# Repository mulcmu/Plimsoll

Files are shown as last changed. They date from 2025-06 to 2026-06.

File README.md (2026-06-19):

# Plimsoll

Prototype designs for klipper load cell ADC implementations.

### Alpha Test

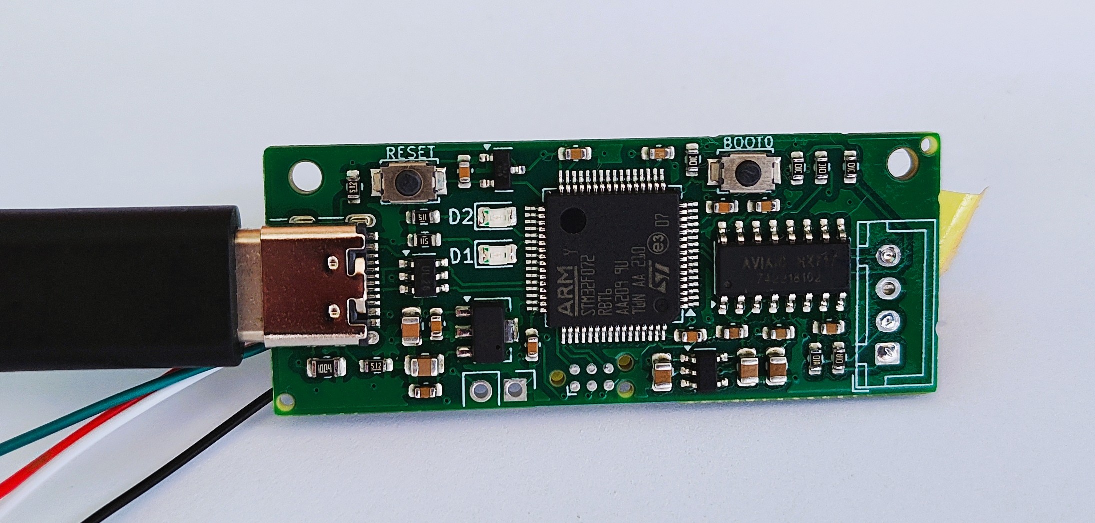
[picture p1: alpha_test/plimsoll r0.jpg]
plimsoll


STM32F072 and HX717 based strain gauge for use as a Klipper load cell.

Initial batch ordered for testing with JLCPCB.  About 5.5 USD cost per board.

Firmware and configuration tested with [current community test branch](https://github.com/garethky/klipper/tree/load-cell-probe-community-testing).

Smallish size, 20x50 mm footprint.  M2.5 mounting holes.  Fab house added the smaller tooling holes...

4 layer PCB all parts on top side.

MCU selected for crystal less USB operation with minimum of 64k flash for firmware.

Separate low noise, high PSRR for analog Vdd supply.

HX717 default data rate 320 Hz.  Adjustable with solder jumpers.

> [!NOTE]
>
> Crystal less main clock is problematic with Klipper and maybe the HX717 code.
>
> Works fine 90% of time, but suffers from occasional timeouts during probes.

### Mini HX717 / Mini ADS1220

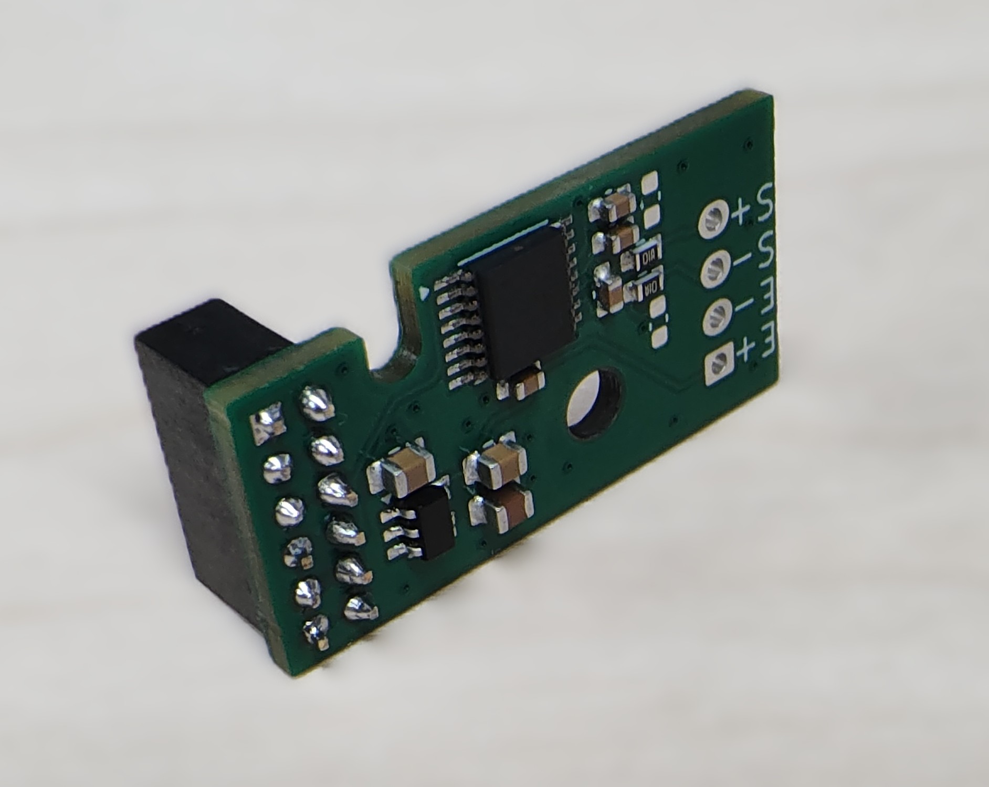
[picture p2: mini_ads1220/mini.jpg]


Addon for a FYSETC H36 **v1** Toolhead board.  Uses the 2x6 2mm expansion pin headers for mounting.  Hardware spi works for the [H36_COMBO](https://wiki.fysetc.com/docs/H36-Combo).  The [H36_COMBO_V2](https://wiki.fysetc.com/docs/H36-Combo-V2) changed the header pins.

Straight needle 2mm 2x6 female pin header (4.3mm plastic body) fits with 6mm standoff but doesn't clear the _IO.0+1_ with a cable installed. A bent needle 2mm 2x6 header works (6mm plastic body) with 8mm standoff after bending the pins to be straight.

4 layer PCB all parts on top side.

Separate low noise, high PSRR for analog Vdd supply.

HX717 data rate 320 Hz.  

Klipper configs for ADS1220/HX717 configs.  
Users have reported __software SPI__ is functional on the v2 boards.

H36 V1
```
sensor_type: ads1220
cs_pin: toolhead:PB6
spi_bus: spi1a
data_ready_pin: toolhead:PC13

sensor_type: hx717
sclk_pin: toolhead:PB3
dout_pin: toolhead:PB4
```

H36 V2
```
sensor_type: ads1220
cs_pin: toolhead:PA14
data_ready_pin: toolhead:PA1
spi_software_sclk_pin:PB7
spi_software_mosi_pin:PB13
spi_software_miso_pin:PA15
spi_speed: 256000

sensor_type: hx717
sclk_pin: toolhead:PB7
dout_pin: toolhead:PA15
```

### 4ch Underbed

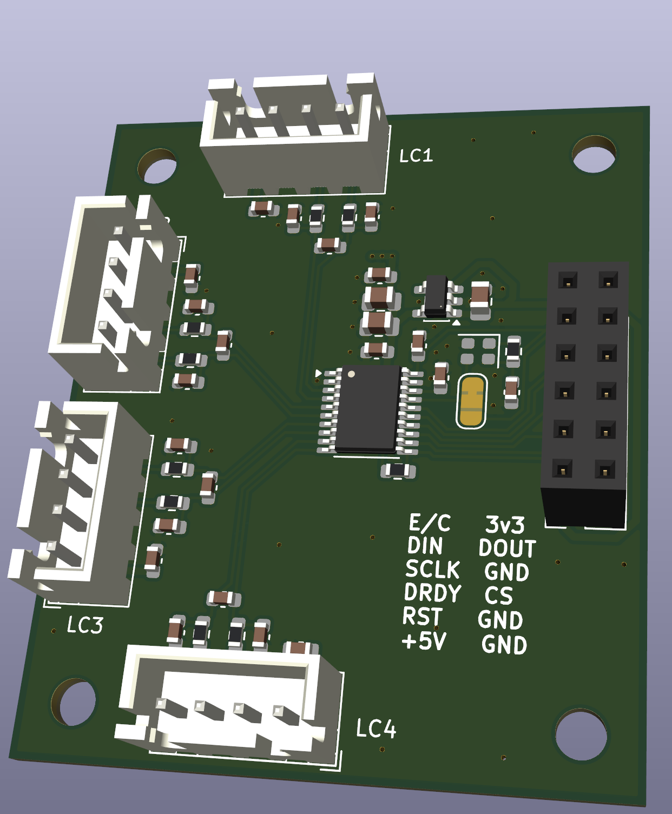
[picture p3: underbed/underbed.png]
mini


4 channel ADS131M04 for underbed applications.  Each load cell can be individually measured and digitally summed.

8.192 MHz clock hardware generator.

Separate low noise, high PSRR for analog Vdd supply.

### Todo:

- [X] Test 2mm pin header fitup on mini pcb
- [x] Test mini ads1220
- [x] Test mini hx717
- [ ] Test underbed pcb
- [ ] ADS131M04 firmware and klipper support

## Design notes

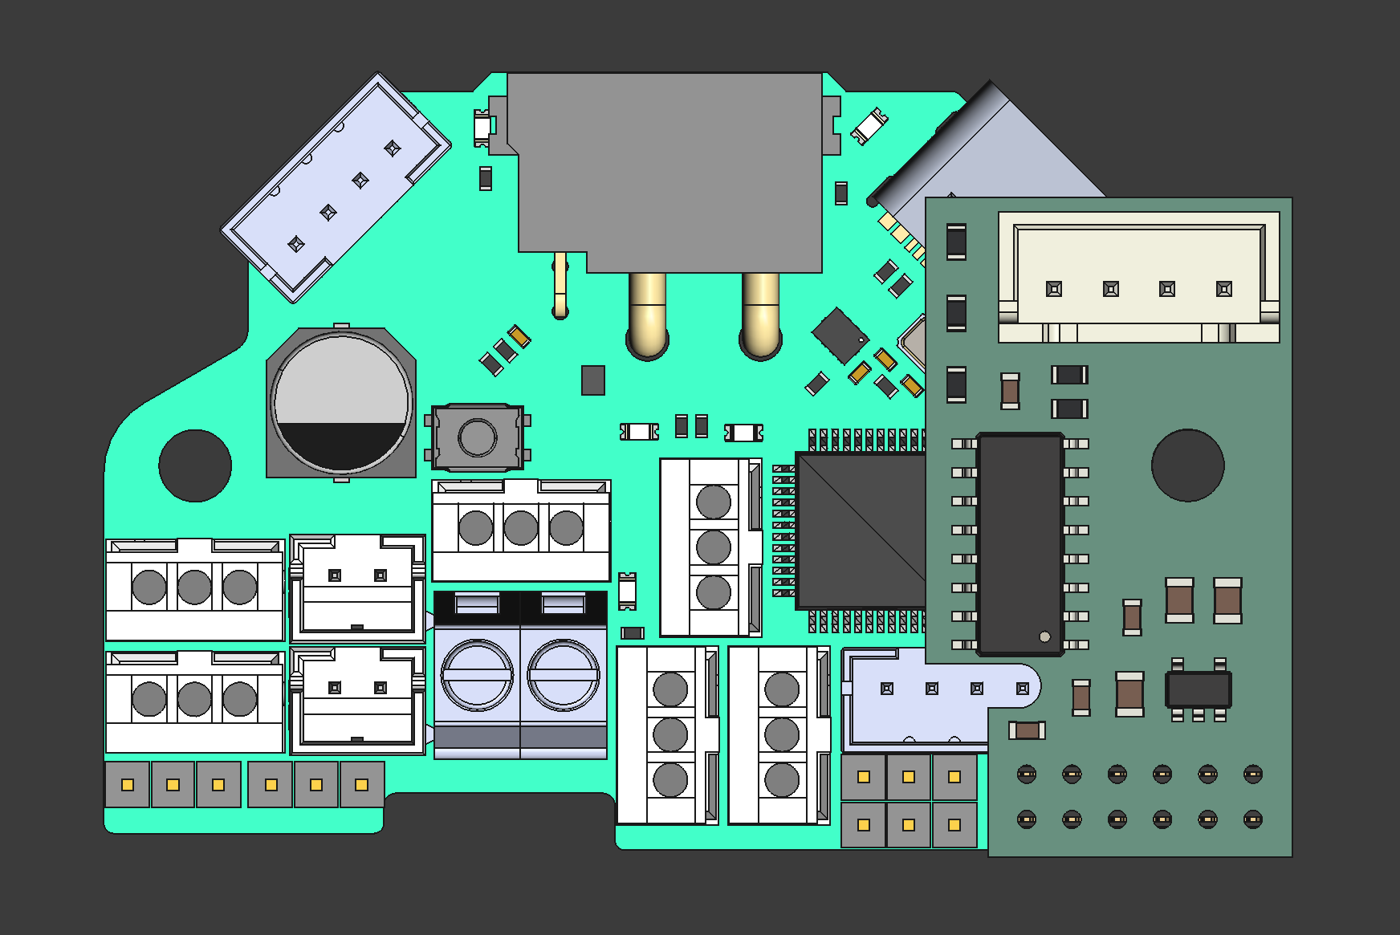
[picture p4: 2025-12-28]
mini_hx717/Screenshot 2025-12-27 220505.png

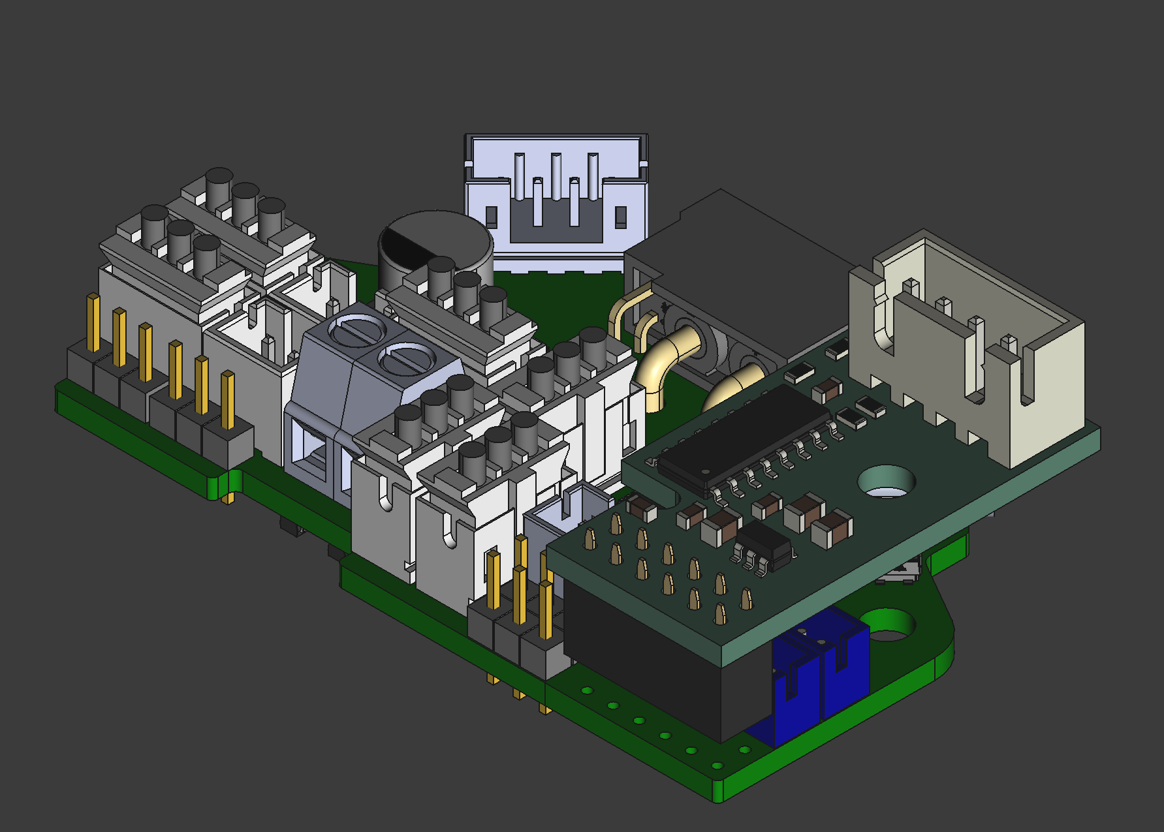
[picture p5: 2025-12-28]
mini_hx717/Screenshot 2025-12-27 220617.png

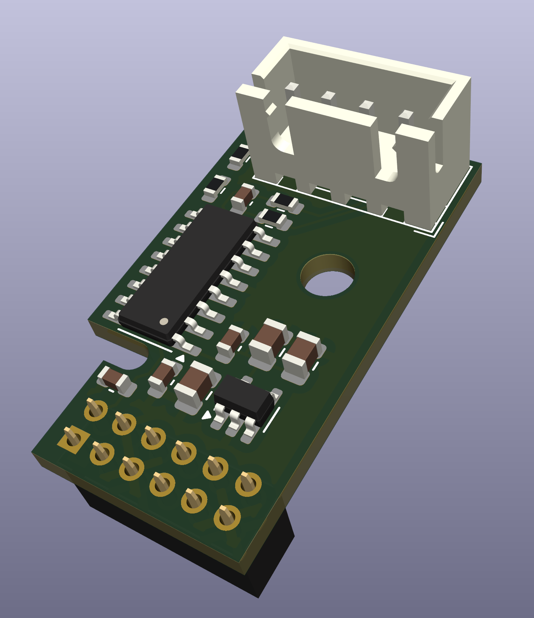
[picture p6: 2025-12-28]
mini_hx717/Screenshot 2025-12-27 220855.png

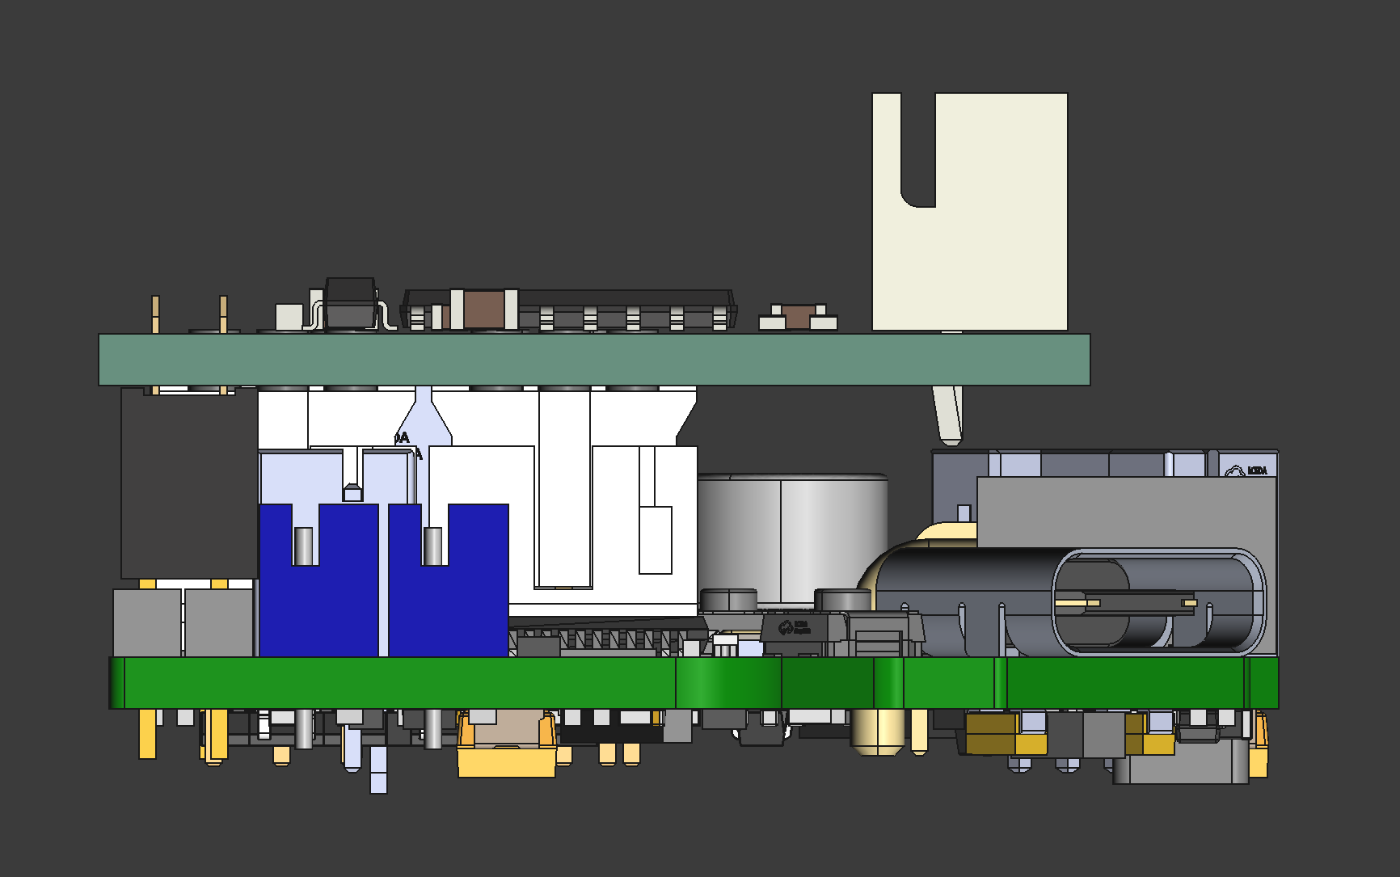
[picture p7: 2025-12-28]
mini_hx717/Screenshot 2025-12-27 220809.png

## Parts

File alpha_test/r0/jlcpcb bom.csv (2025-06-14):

Value | Reference | Footprint | LCSC PN
100n | C1 C3 C5 C7 C8 C9 C12 C13 C14 C15 C16 C17 | Capacitor_SMD:C_0603_1608Metric | C14663
10u | C2 C4 C11 | Capacitor_SMD:C_0805_2012Metric | C15850
1u | C6 C10 | Capacitor_SMD:C_0805_2012Metric | C28323
GRN | D1 D2 | LED_SMD:LED_0805_2012Metric | C2297
USB_C | J2 | Connector_USB:USB_C_Receptacle_G-Switch_GT-USB-7010ASV | C2988369
1M | R1 | Resistor_SMD:R_0805_2012Metric | C17514
10k | R4 R10 R11 R12 | Resistor_SMD:R_0603_1608Metric | C25804
5k1 | R5 R6 | Resistor_SMD:R_0603_1608Metric | C23186
100 | R7 R8 | Resistor_SMD:R_0603_1608Metric | C22775
510 | R13 R14 | Resistor_SMD:R_0603_1608Metric | C23193
RESET | SW1 | plimsoll-Library:push_button | C720477
BOOT0 | SW2 | plimsoll-Library:push_button | C720477
USBLC6-2SC6 | U1 | Package_TO_SOT_SMD:SOT-23-6 | C7519
APX803L20-29SA-7 | U2 | Package_TO_SOT_SMD:SOT-23 | C2067355
STM32F072RBTx | U3 | Package_QFP:LQFP-64_10x10mm_P0.5mm | C46046
AP2205-3.3 | U4 | Package_TO_SOT_SMD:SOT-89-3 | C5205181
RS3236-3.3 | U5 | Package_TO_SOT_SMD:SOT-23-5 | C379349
HX717 | U6 | Package_SO:SOP-16_3.9x9.9mm_P1.27mm | C575394

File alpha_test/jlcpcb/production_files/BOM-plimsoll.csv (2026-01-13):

Comment | Designator | Footprint | LCSC | Quantity
100n | C1,C13,C14,C15,C16,C17,C3,C5 | C_0603_1608Metric | C14663 | 8
10k | R4 | R_0603_1608Metric | C25804 | 1
10u | C2,C4 | C_0805_2012Metric | C15850 | 2
1M | R1 | R_0805_2012Metric | C17514 | 1
20pf | C7,C8 | C_0603_1608Metric | C14663 | 2
510 | R13,R14 | R_0603_1608Metric | C23193 | 2
5k1 | R5,R6 | R_0603_1608Metric | C23186 | 2
AP2205-3.3 | U4 | SOT-89-3 | C5205181 | 1
APX803L20-29SA-7 | U2 | SOT-23 | C2067355 | 1
BOOT0 | BOOT | push_button | C720477 | 1
GRN | D1,D2 | LED_0805_2012Metric | C2297 | 2
RESET | RESET | push_button | C720477 | 1
STM32F072RBTx | U3 | LQFP-64_10x10mm_P0.5mm | C46046 | 1
USBLC6-2SC6 | U1 | SOT-23-6 | C7519 | 1
USB_C | J2 | USB_C_Receptacle_G-Switch_GT-USB-7010ASV | C2988369 | 1
Crystal_GND24 | Y2 | Crystal_SMD_3225-4Pin_3.2x2.5mm_HandSoldering |  | 1
Conn_01x18 | J3 | PinHeader_1x18_P2.54mm_Vertical |  | 1
Conn_01x18 | J7 | PinHeader_1x18_P2.54mm_Vertical |  | 1
Conn_01x18 | J6 | PinHeader_1x18_P2.54mm_Vertical |  | 1
Conn_01x18 | J5 | PinHeader_1x18_P2.54mm_Vertical |  | 1

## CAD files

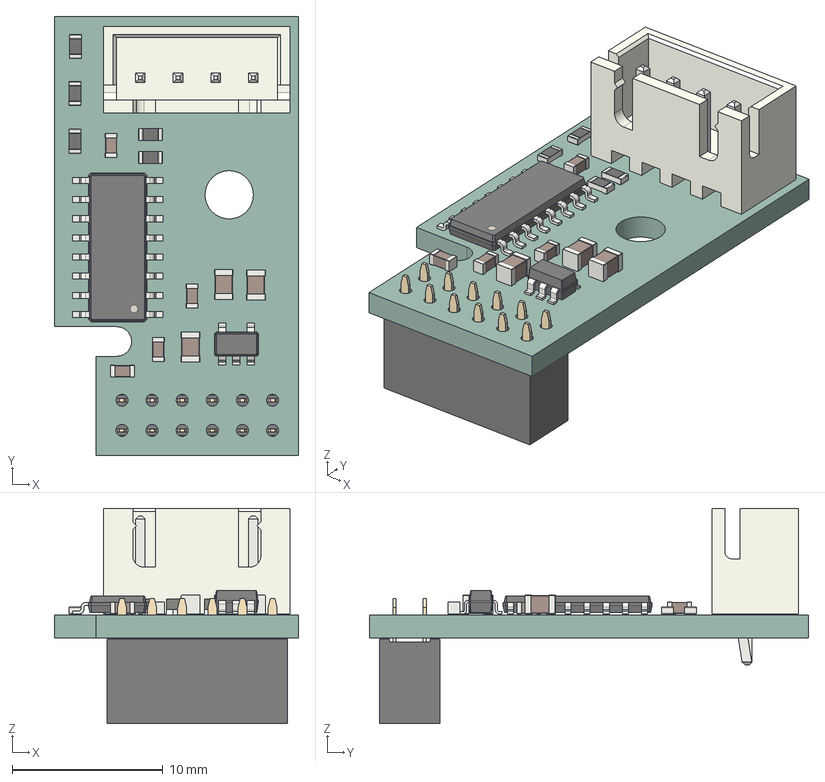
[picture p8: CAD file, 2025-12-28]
mini_hx717/plimsoll.step
16.2 x 29.1 x 14.3 mm
R_0603_1608Metric x 5
JST_XH_B4B-XH-A_1x04_P2.50mm_Vertical
C_0603_1608Metric x 4
C_0805_2012Metric x 3
SOT-23-5
SOP-16_3.9x9.9mm_P1.27mm
PinSocket_2x06_P2.00mm_Vertical
plimsoll_PCB

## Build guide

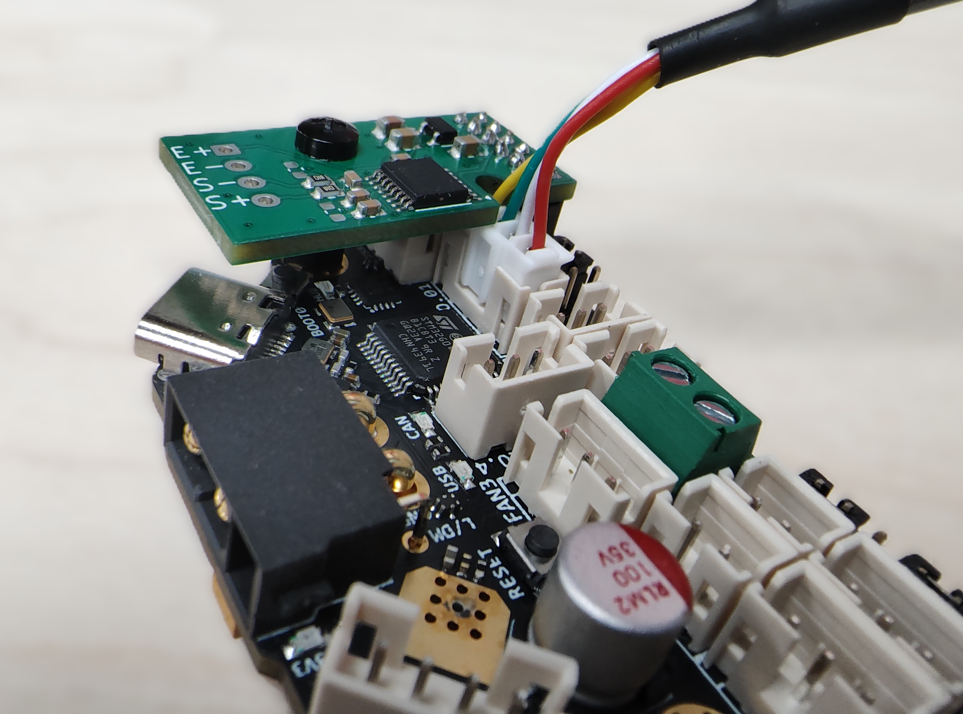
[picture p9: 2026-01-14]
mini_ads1220/installed.jpg

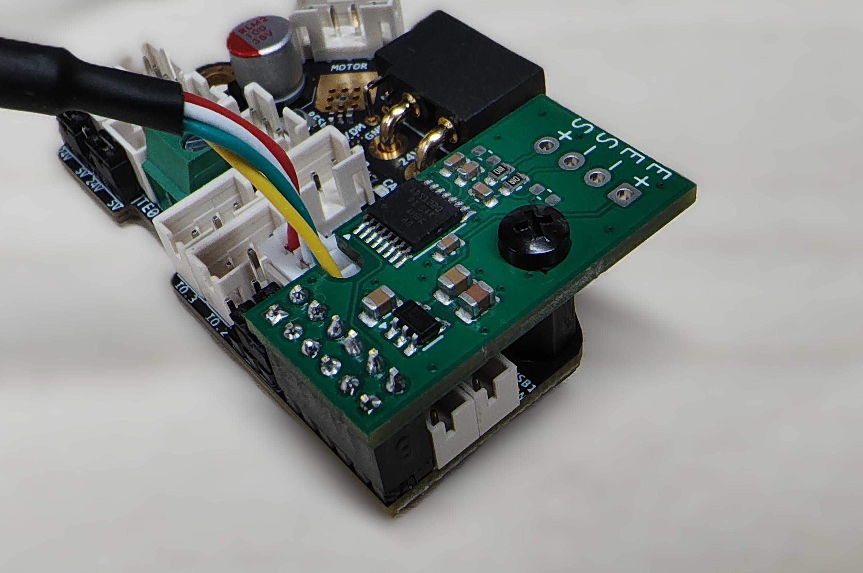
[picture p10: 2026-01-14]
mini_ads1220/installed2.jpg

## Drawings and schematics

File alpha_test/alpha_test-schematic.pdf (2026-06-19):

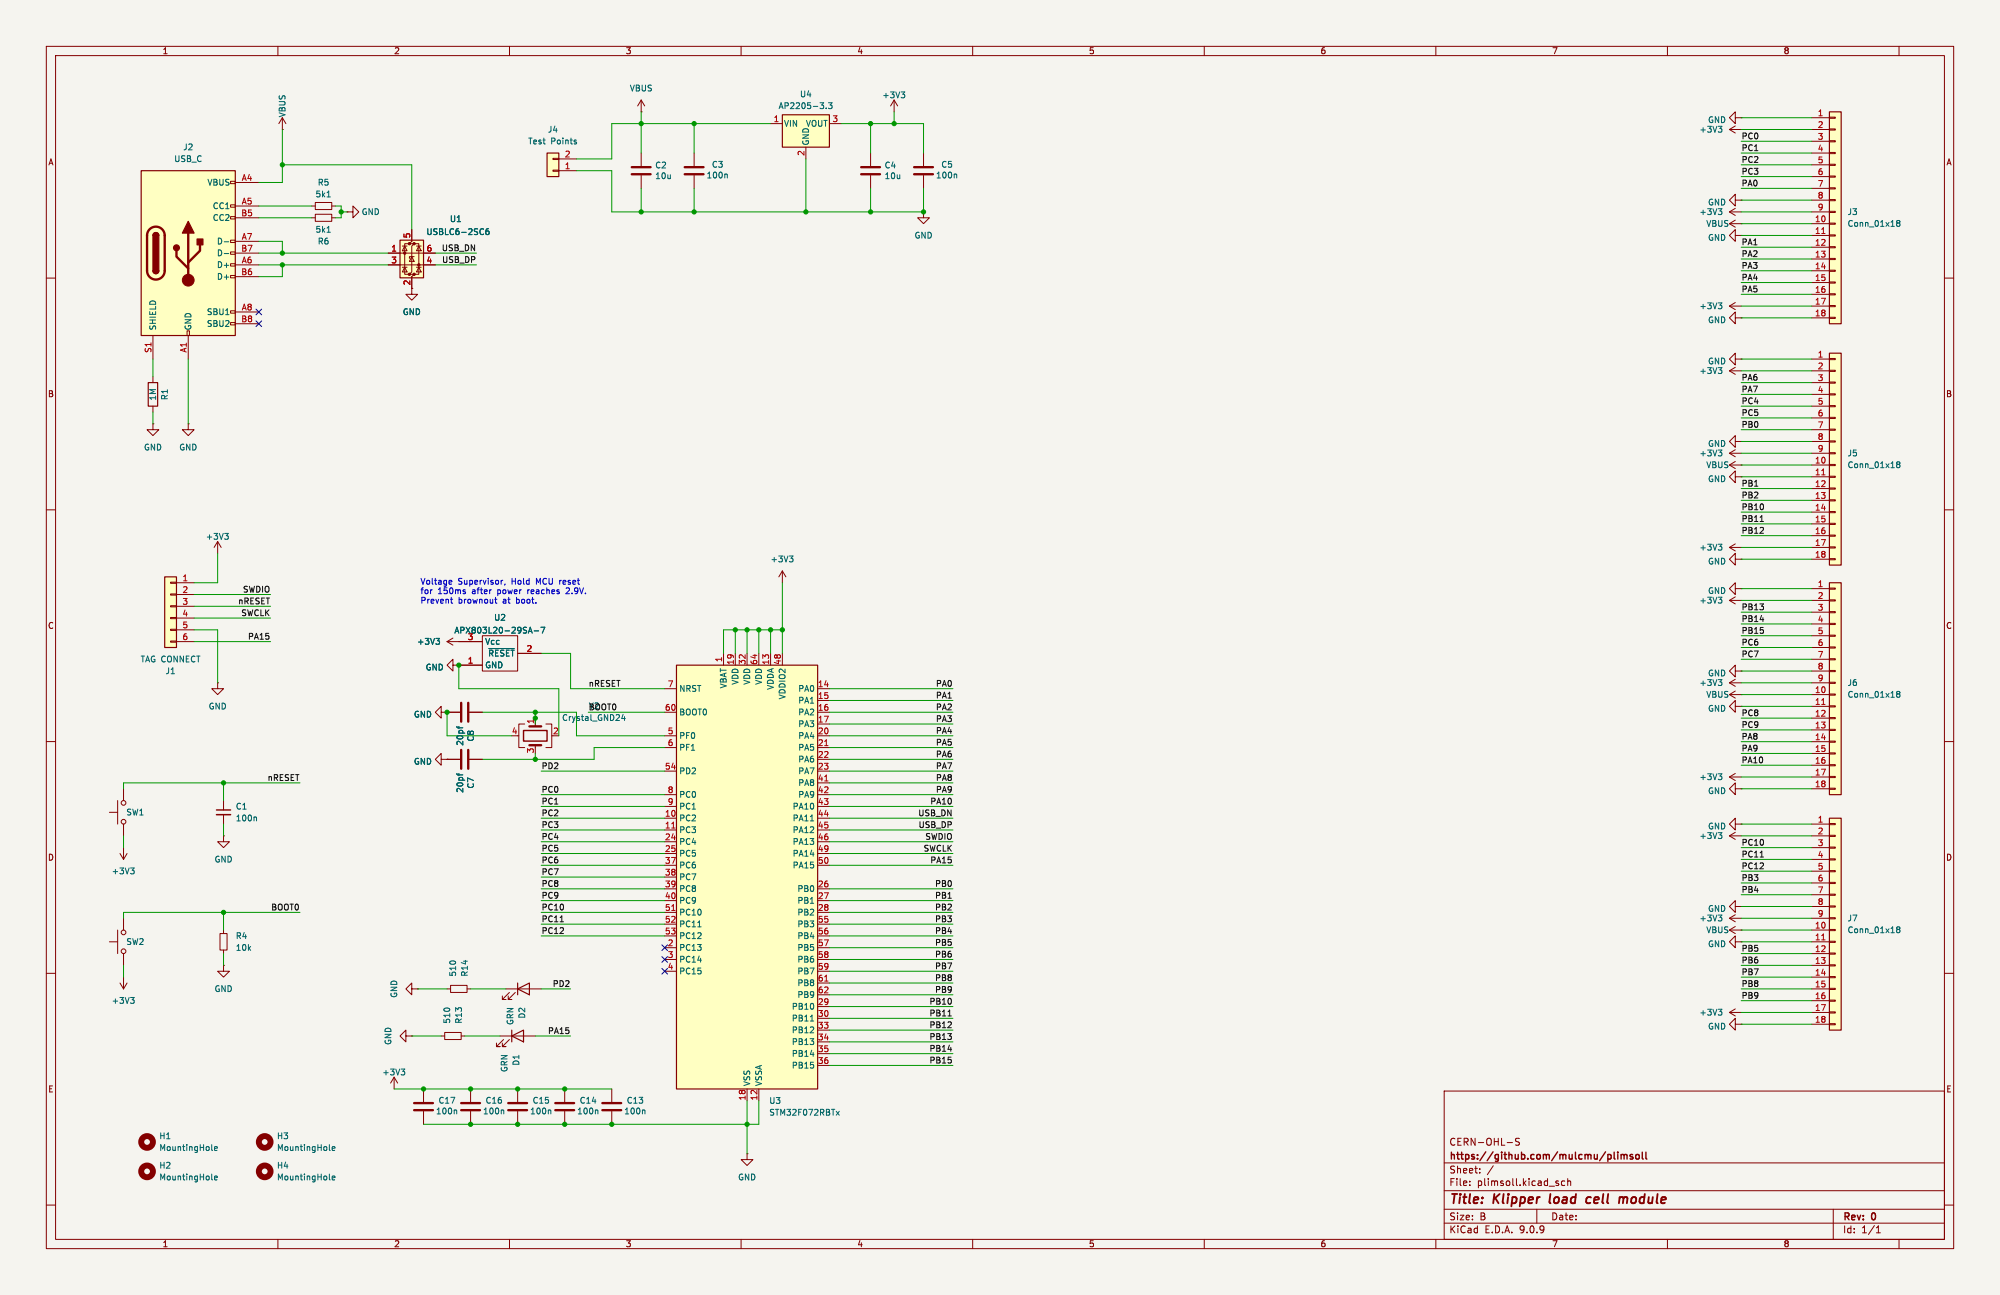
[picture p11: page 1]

File: plimsoll.kicad_sch Sheet: / https://github.com/mulcmu/plimsoll CERN-OHL-S

Id: 1/1 Title: Klipper load cell module

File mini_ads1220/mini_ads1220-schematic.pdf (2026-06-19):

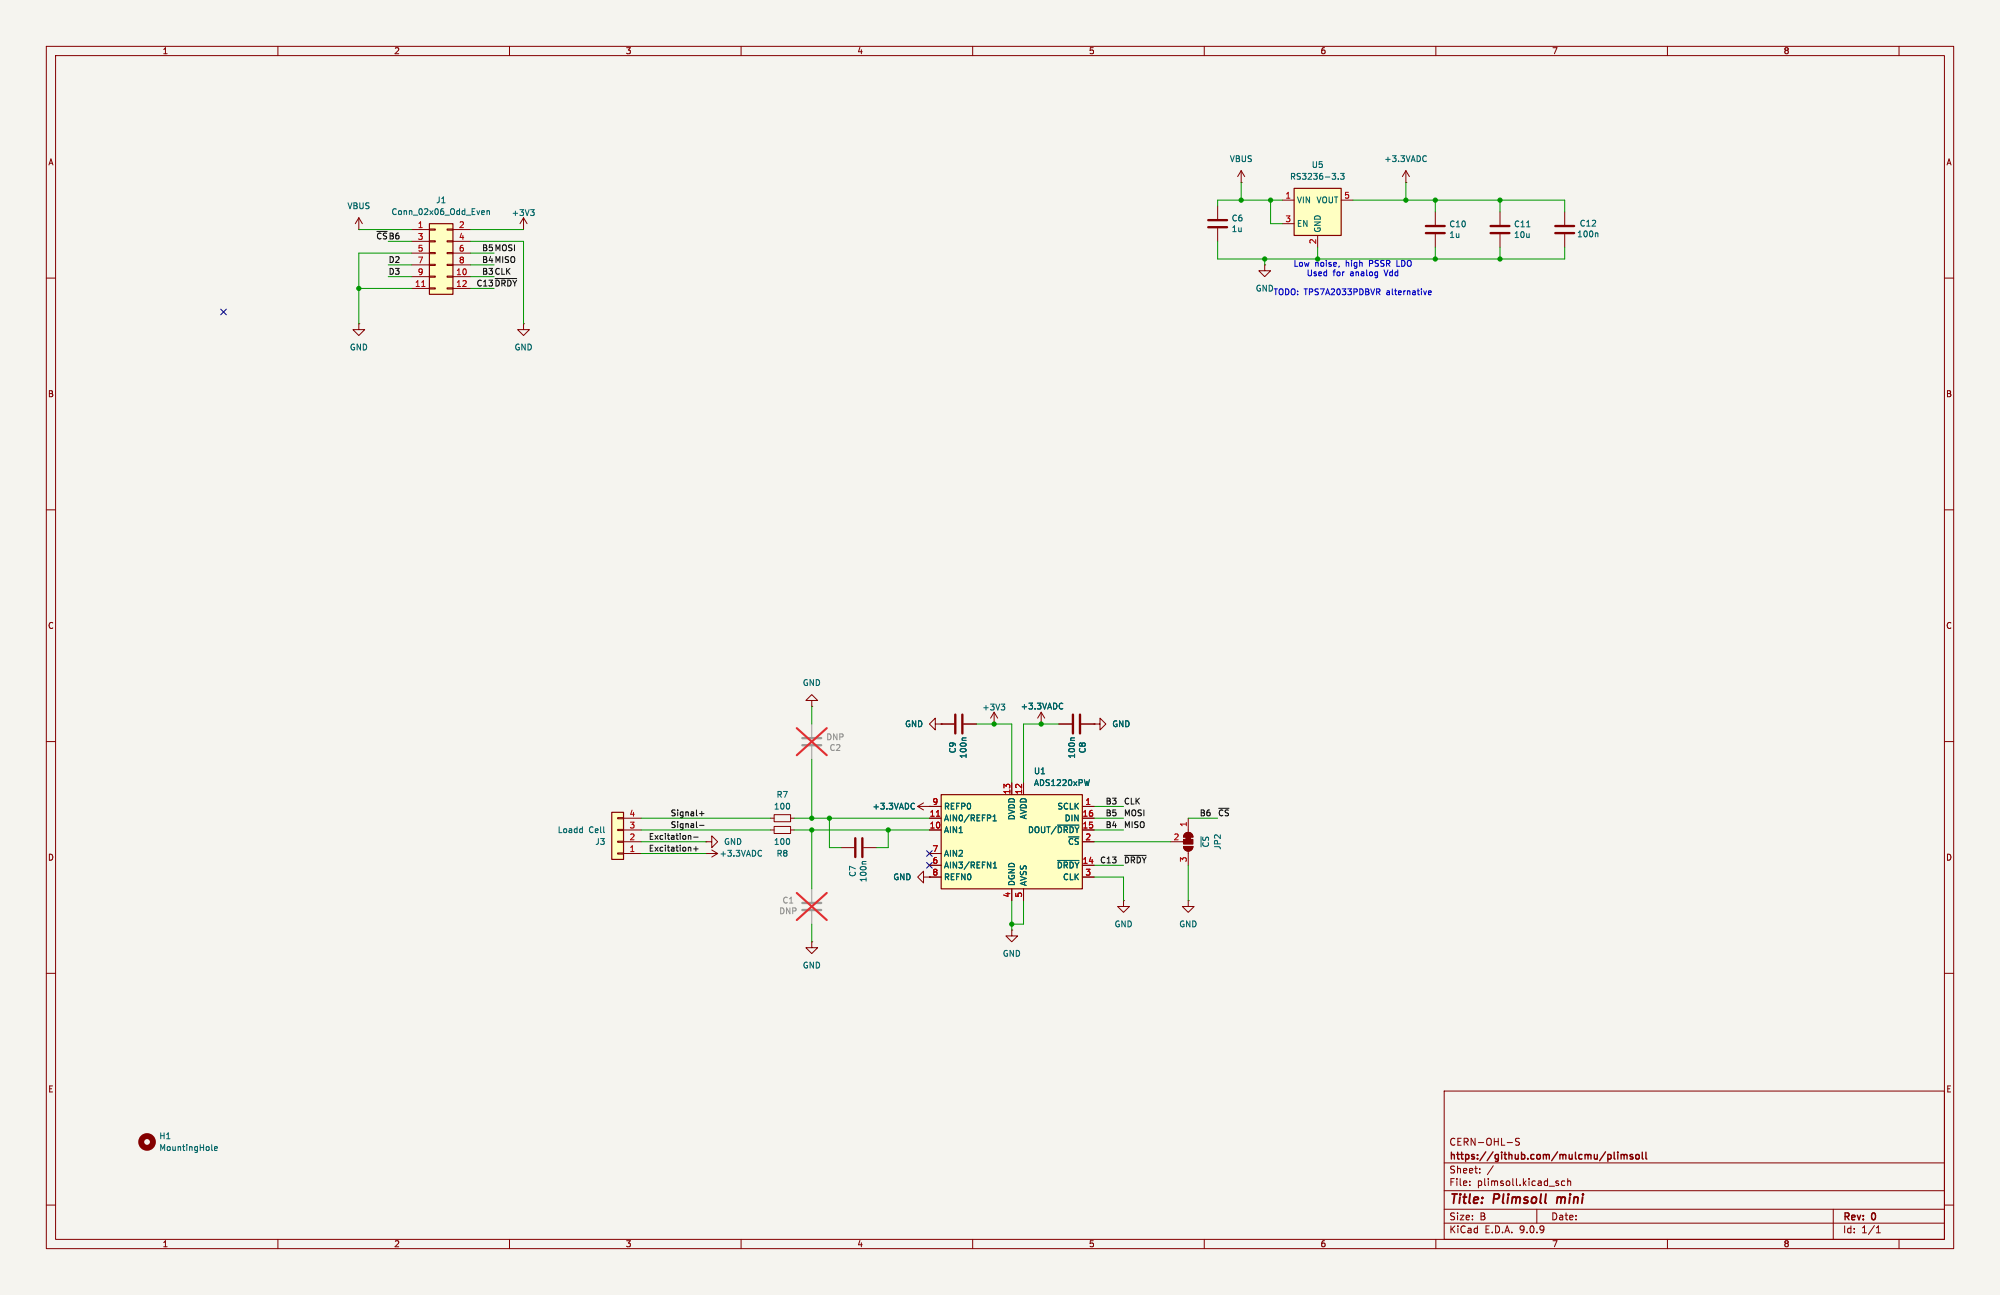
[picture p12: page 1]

Low noise, high PSSR LDO

5 SCLK 1 DIN 16 DOUT/~{DRDY}15 ~{CS}2 ~{DRDY} 14 CLK 3 +3.3VADC C8 100n +3.3VADC

5 SCLK 1 DIN 16 DOUT/~{DRDY}15 ~{CS}2 ~{DRDY} 14 CLK 3 U1ADS1220xPW

Id: 1/1 Title: Plimsoll mini File: plimsoll.kicad_sch Sheet: / https://github.com/mulcmu/plimsoll CERN-OHL-S C7 100n GND

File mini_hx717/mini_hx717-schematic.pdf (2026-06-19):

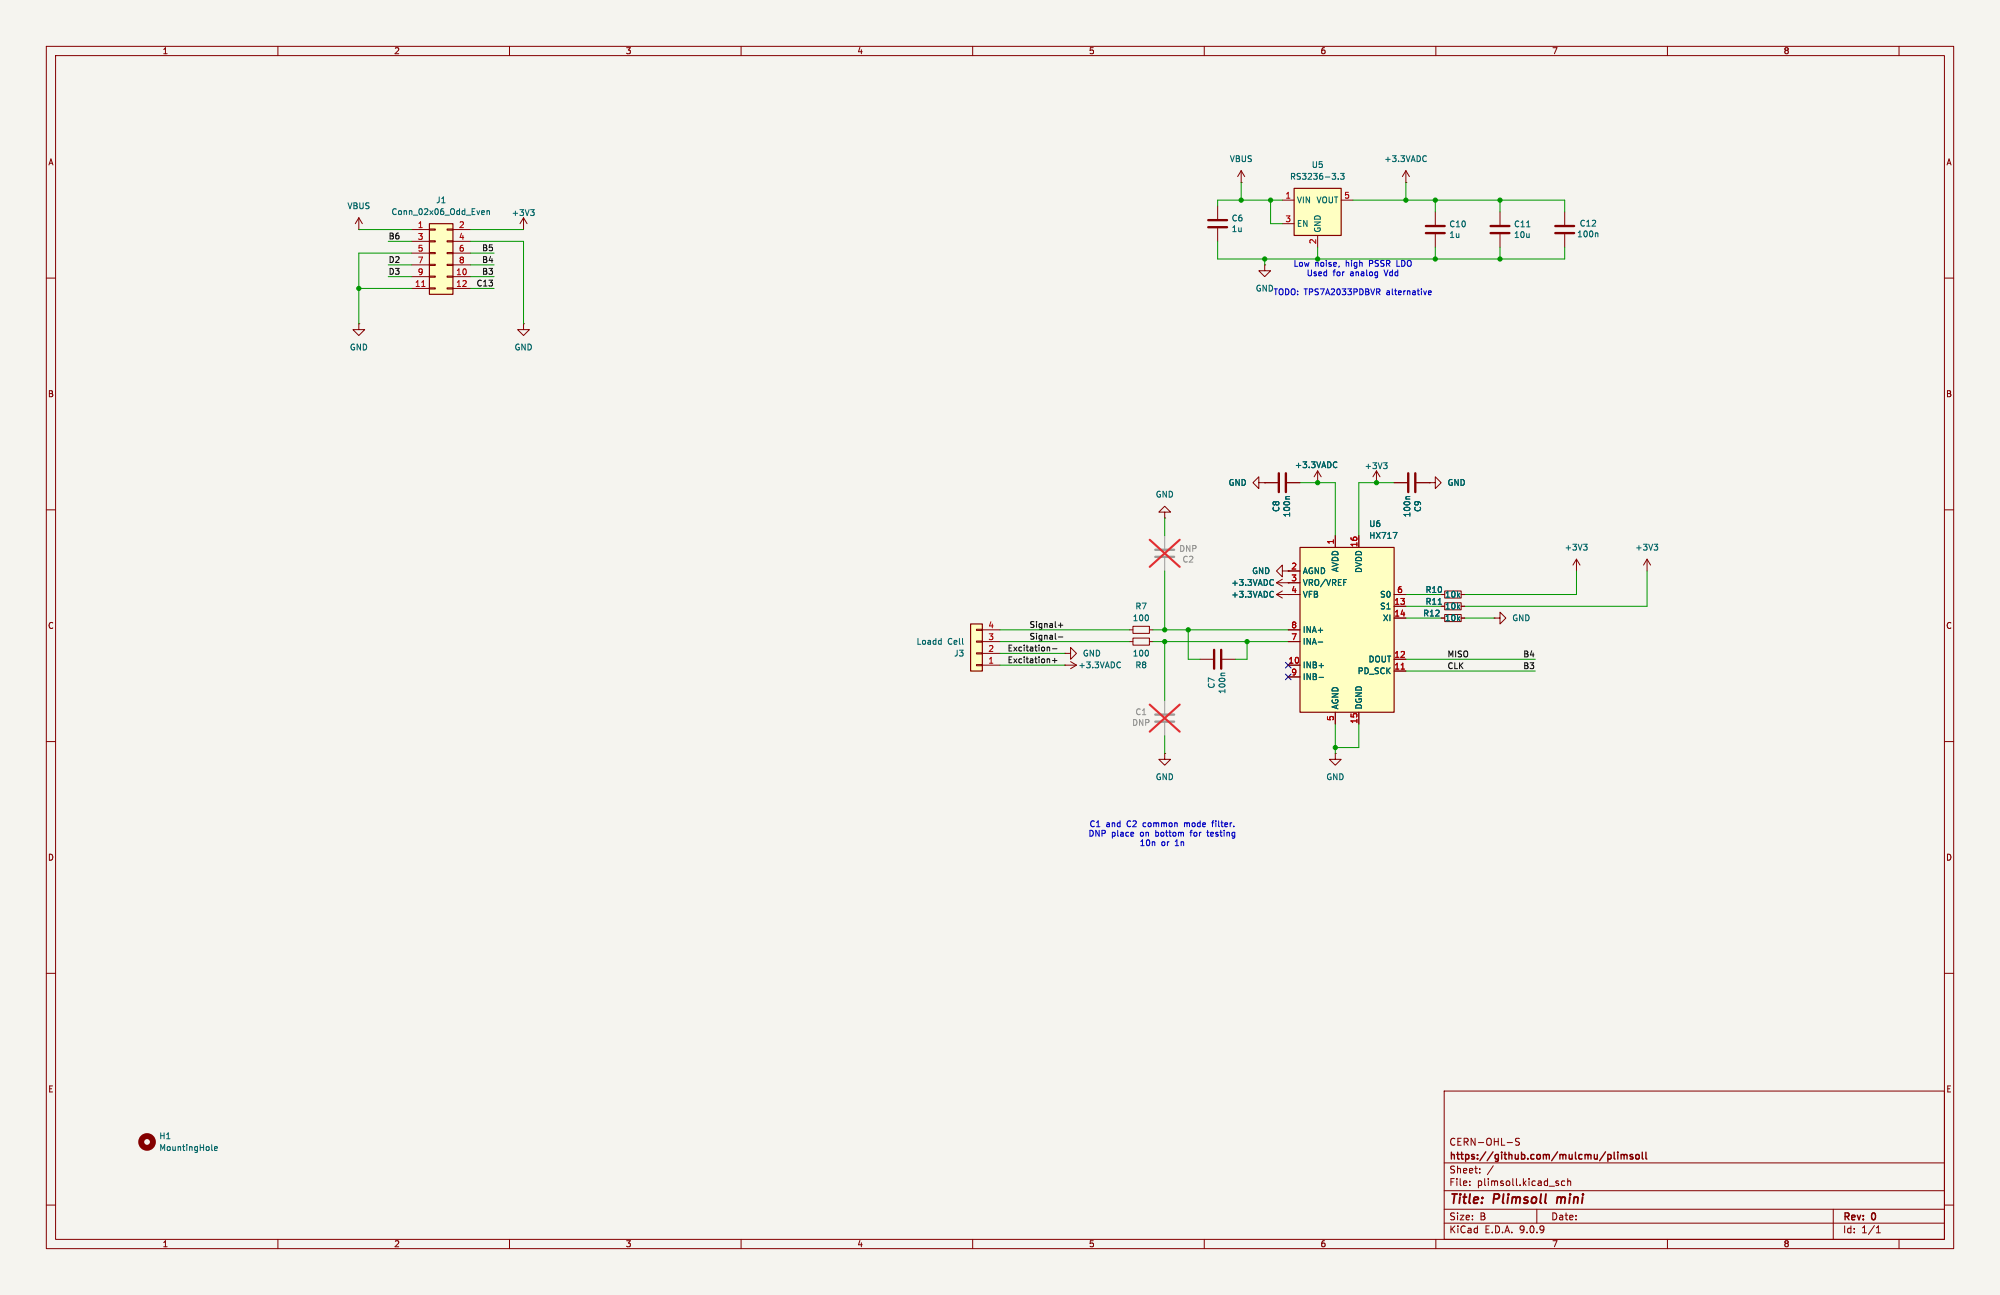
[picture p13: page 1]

Low noise, high PSSR LDO

Used for analog Vdd TODO: TPS7A2033PDBVR alternative C1 and C2 common mode filter. DNP place on bottom for testing

5 DVDD 16 DGND 15 S0 6 S1 13 XI 14 DOUT 12 PD_SCK 11 C8 100n GND

5 DVDD 16 DGND 15 S0 6 S1 13 XI 14 DOUT 12 PD_SCK 11 U6 HX717 +3.3VADC

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

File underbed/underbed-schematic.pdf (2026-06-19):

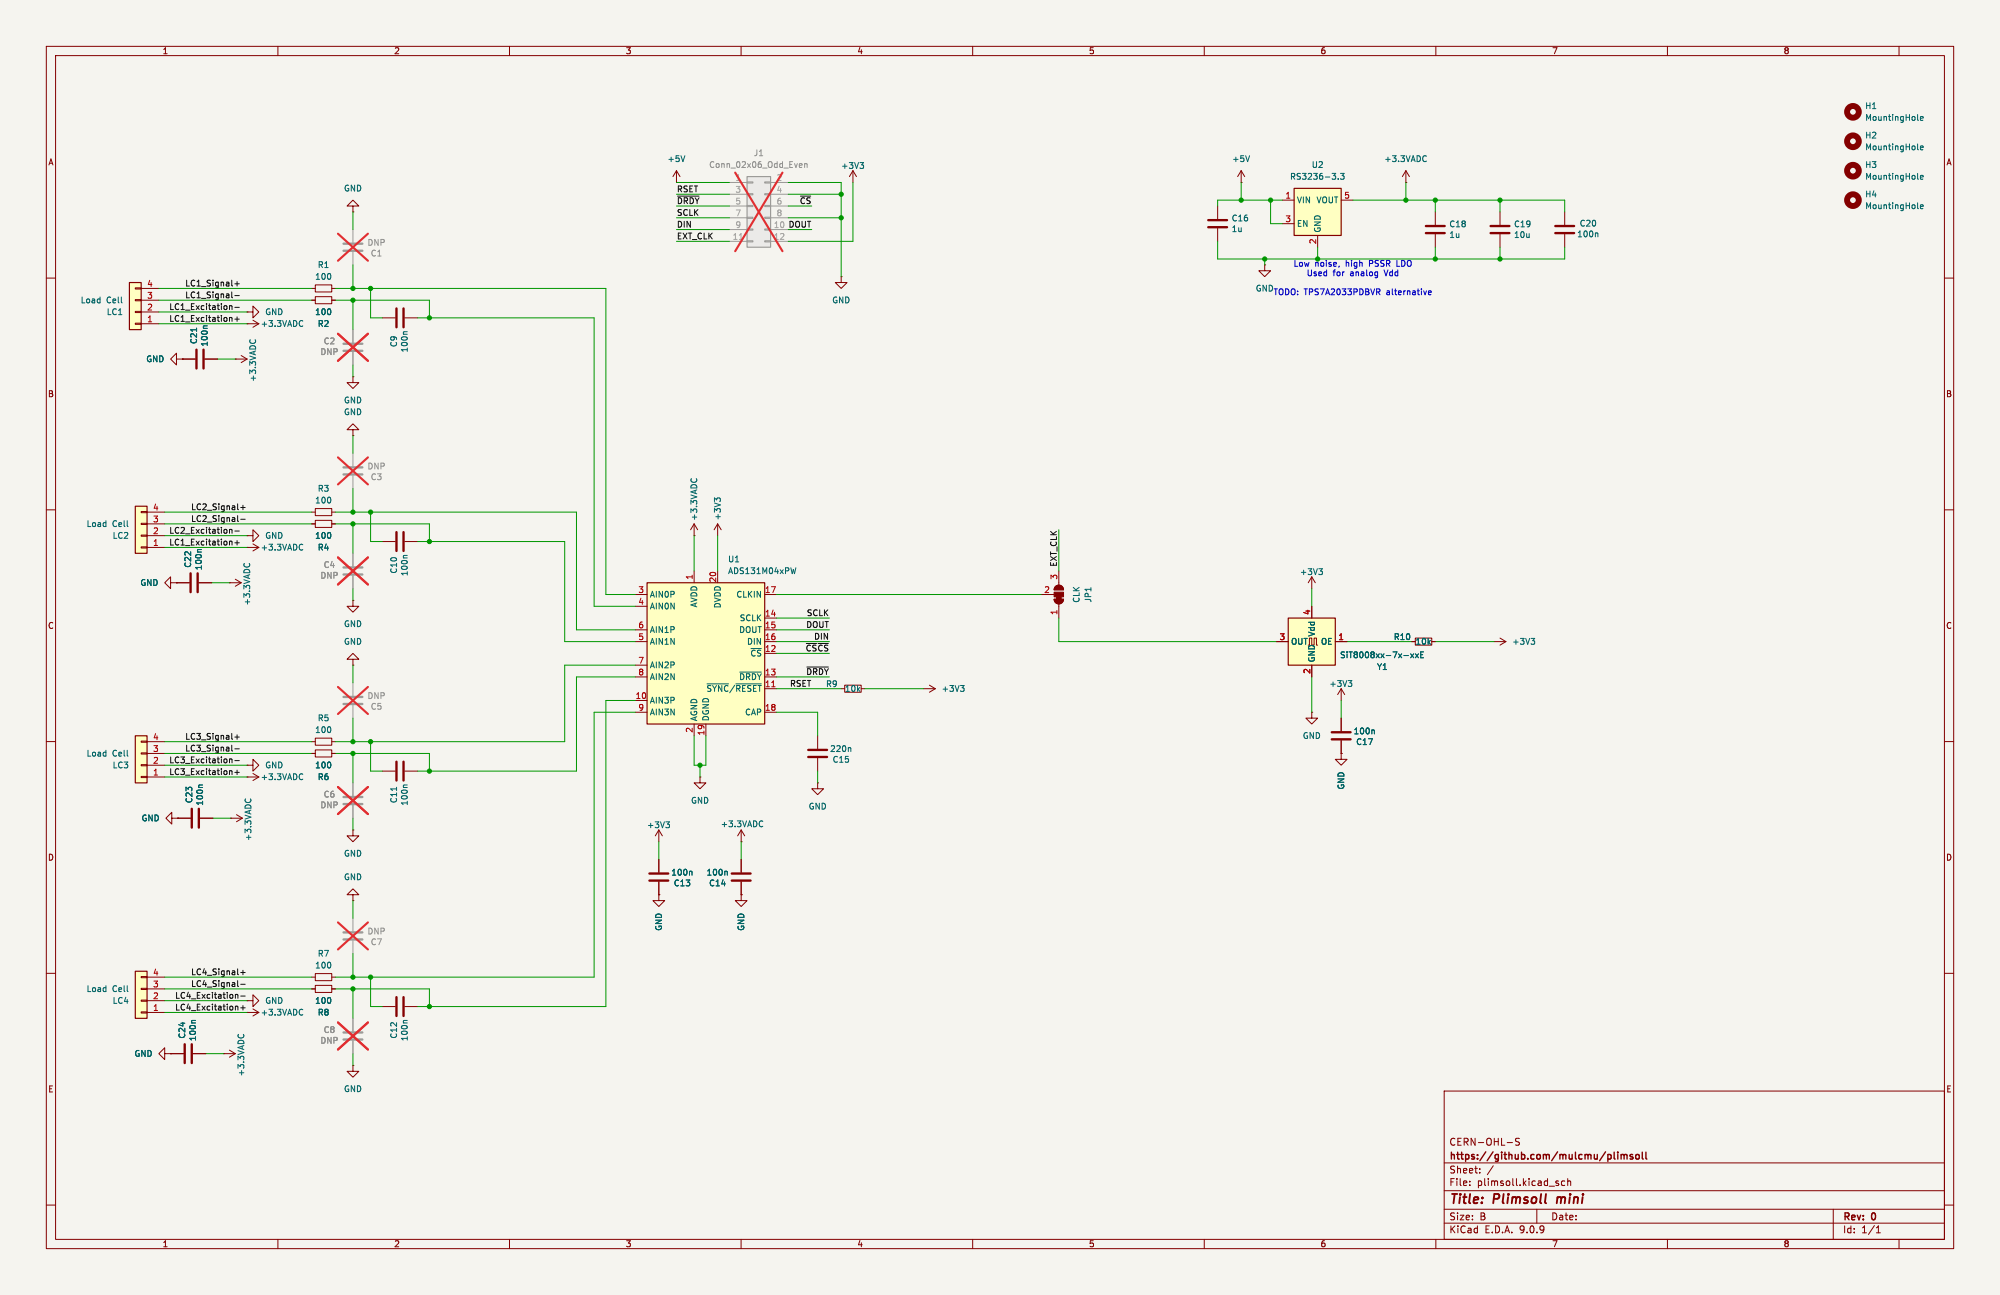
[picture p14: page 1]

H3 MountingHole H2 MountingHole H4 MountingHole GND
Used for analog Vdd TODO: TPS7A2033PDBVR alternative C17

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

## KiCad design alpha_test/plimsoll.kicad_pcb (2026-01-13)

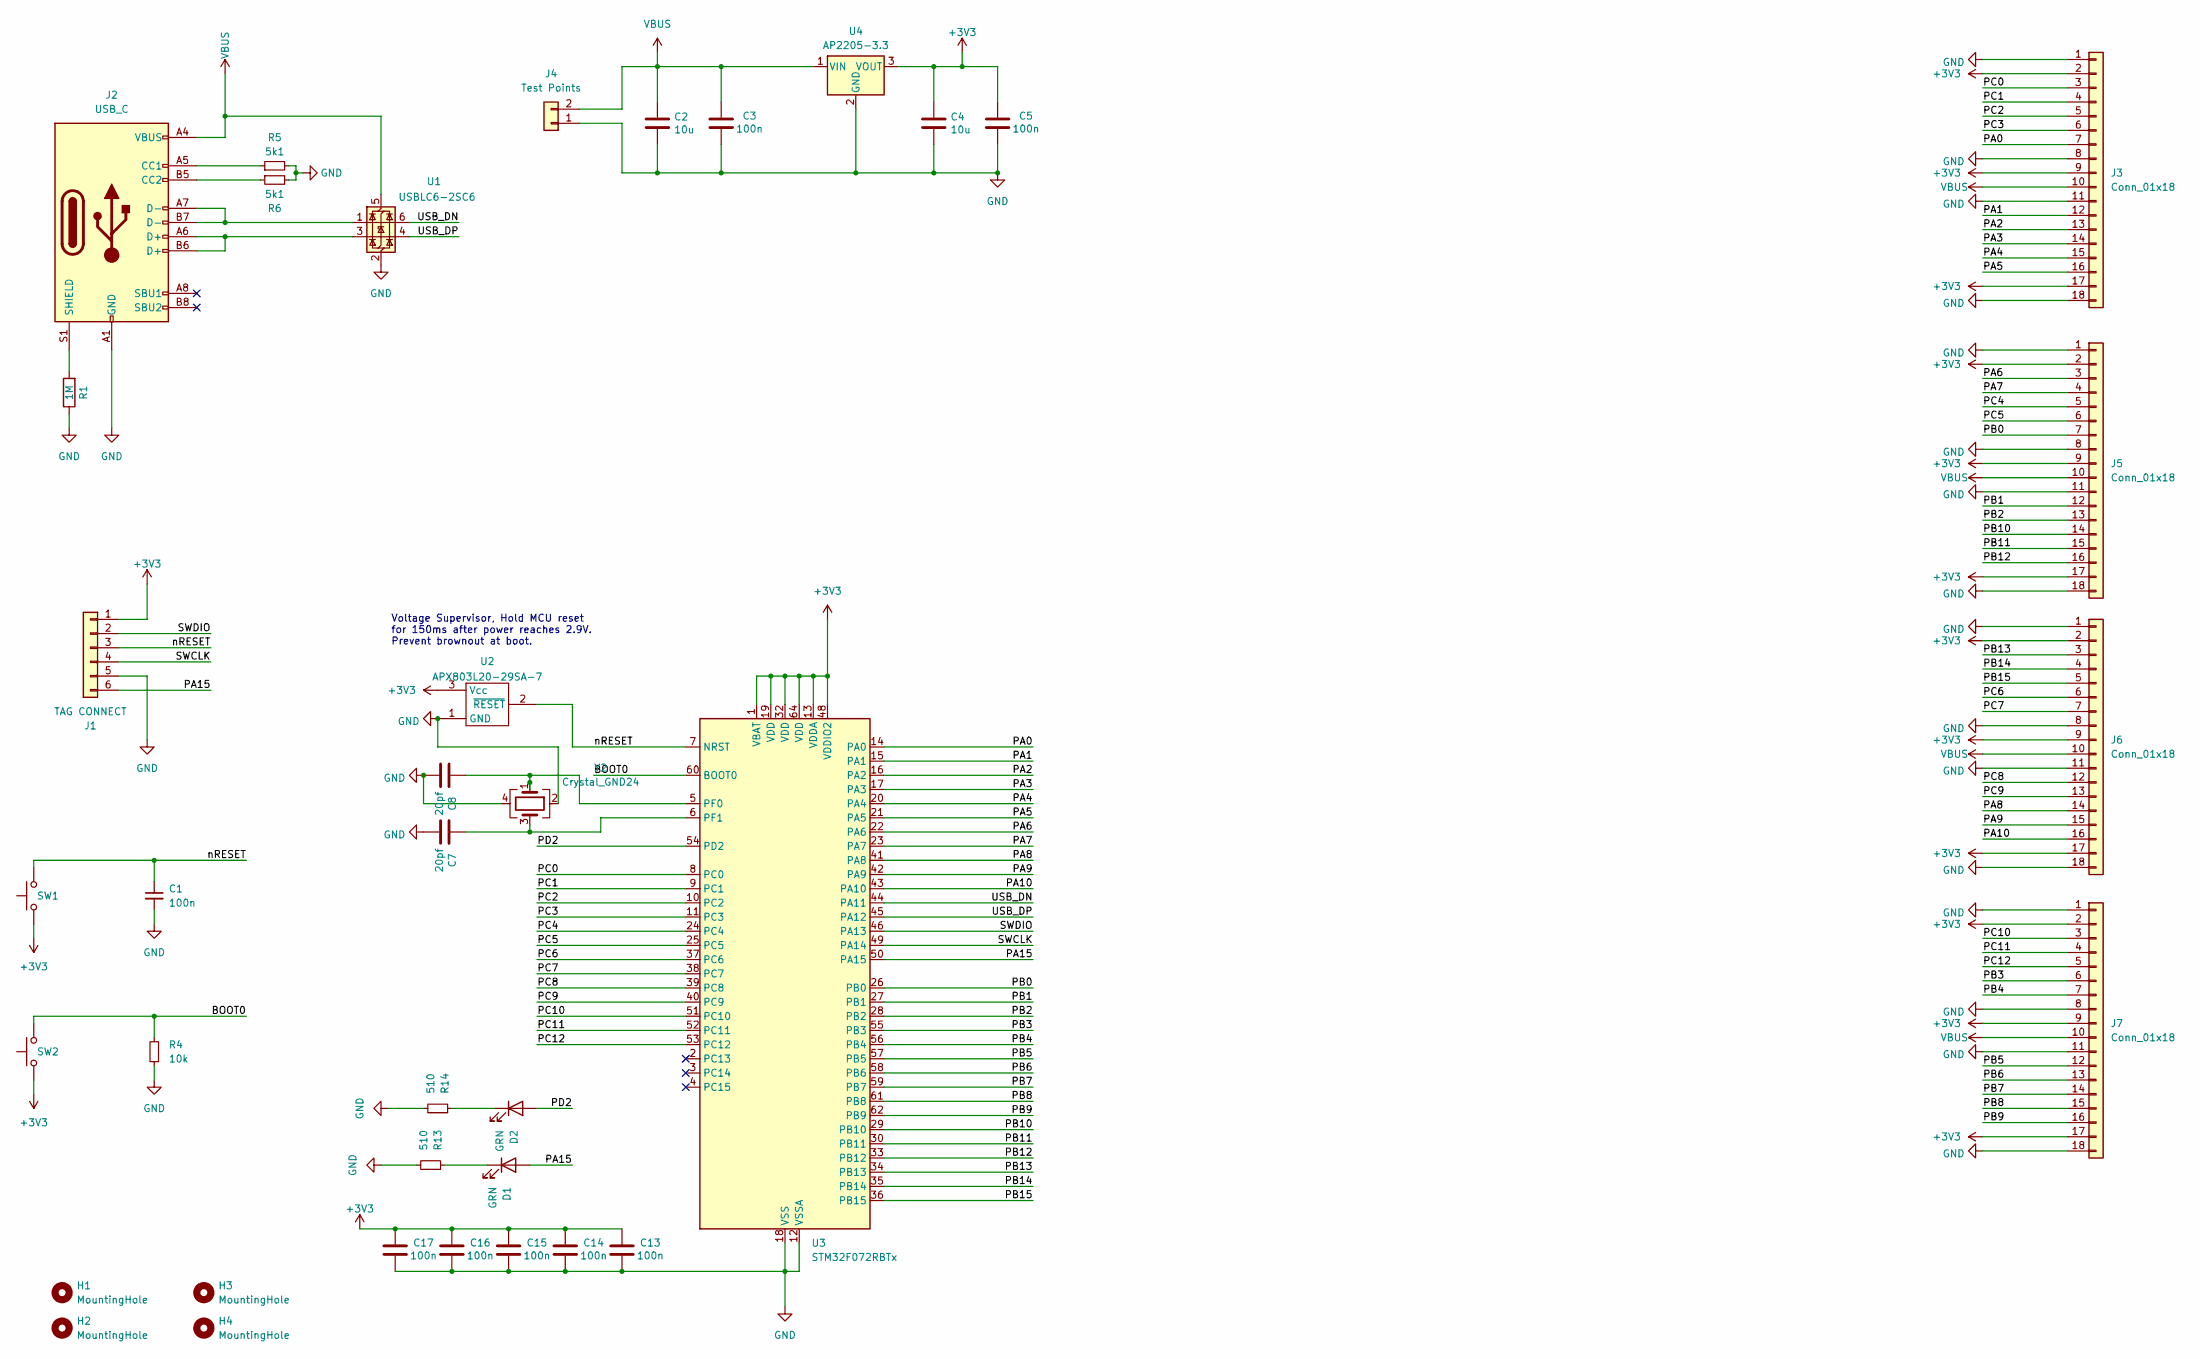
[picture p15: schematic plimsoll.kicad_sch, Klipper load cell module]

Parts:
C1, C3, C5, C13, C14, C15, C16, C17: 100n; C_0603_1608Metric; LCSC PN C14663
C2, C4: 10u; C_0805_2012Metric; LCSC PN C15850
C7, C8: 20pf; C_0603_1608Metric; LCSC PN C14663
D1, D2: GRN; LED_0805_2012Metric; LCSC PN C2297
H1, H2, H3, H4: MountingHole; MountingHole_2.2mm_M2_ISO7380
J1: TAG CONNECT; Tag-Connect_TC2030-IDC-NL_2x03_P1.27mm_Vertical
J2: USB_C; USB_C_Receptacle_G-Switch_GT-USB-7010ASV; LCSC PN C2988369
J3, J5, J6, J7: Conn_01x18; PinHeader_1x18_P2.54mm_Vertical
J4: Test Points; PinHeader_1x02_P2.54mm_Vertical
R1: 1M; R_0805_2012Metric; LCSC PN C17514
R4: 10k; R_0603_1608Metric; LCSC PN C25804
R5, R6: 5k1; R_0603_1608Metric; LCSC PN C23186
R13, R14: 510; R_0603_1608Metric; LCSC PN C23193
SW1: RESET; push_button; LCSC PN C720477
SW2: BOOT0; push_button; LCSC PN C720477
U1: USBLC6-2SC6; SOT-23-6; LCSC PN C7519
U2: APX803L20-29SA-7; SOT-23; LCSC PN C2067355
U3: STM32F072RBTx; LQFP-64_10x10mm_P0.5mm; LCSC PN C46046
U4: AP2205-3.3; SOT-89-3; LCSC PN C5205181
Y2: Crystal_GND24; Crystal_SMD_3225-4Pin_3.2x2.5mm_HandSoldering

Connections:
+3V3: C4.1, C5.2, C13.2, C14.2, C15.2, C16.2, C17.2, J1.1, J3.2, J3.9, J3.17, J5.2, J5.9, J5.17, J6.2, J6.9, J6.17, J7.2, J7.9, J7.17, SW1.1, SW2.1, U2.3 (Vcc), U3.1 (VBAT), U3.13 (VDDA), U3.19 (VDD), U3.32 (VDD), U3.48 (VDDIO2), U3.64 (VDD), U4.3 (VOUT); also elsewhere on the board
/BOOT0: R4.2, SW2.2, U3.60 (BOOT0); also elsewhere on the board
/PA0: J3.7, U3.14 (PA0)
/PA1: J3.12, U3.15 (PA1)
/PA2: J3.13, U3.16 (PA2)
/PA3: J3.14, U3.17 (PA3)
/PA4: J3.15, U3.20 (PA4)
/PA5: J3.16, U3.21 (PA5)
/PA6: J5.3, U3.22 (PA6)
/PA7: J5.4, U3.23 (PA7)
/PA8: J6.14, U3.41 (PA8)
/PA9: J6.15, U3.42 (PA9)
/PA10: J6.16, U3.43 (PA10)
/PA15: D1.2 (A), J1.6, U3.50 (PA15)
/PB0: J5.7, U3.26 (PB0)
/PB1: J5.12, U3.27 (PB1)
/PB2: J5.13, U3.28 (PB2)
/PB3: J7.6, U3.55 (PB3)
/PB4: J7.7, U3.56 (PB4)
/PB5: J7.12, U3.57 (PB5)
/PB6: J7.13, U3.58 (PB6)
/PB7: J7.14, U3.59 (PB7)
/PB8: J7.15, U3.61 (PB8)
/PB9: J7.16, U3.62 (PB9)
/PB10: J5.14, U3.29 (PB10)
/PB11: J5.15, U3.30 (PB11)
/PB12: J5.16, U3.33 (PB12)
/PB13: J6.3, U3.34 (PB13)
/PB14: J6.4, U3.35 (PB14)
/PB15: J6.5, U3.36 (PB15)
/PC0: J3.3, U3.8 (PC0)
/PC1: J3.4, U3.9 (PC1)
/PC2: J3.5, U3.10 (PC2)
/PC3: J3.6, U3.11 (PC3)
/PC4: J5.5, U3.24 (PC4)
/PC5: J5.6, U3.25 (PC5)
/PC6: J6.6, U3.37 (PC6)
/PC7: J6.7, U3.38 (PC7)
/PC8: J6.12, U3.39 (PC8)
/PC9: J6.13, U3.40 (PC9)
/PC10: J7.3, U3.51 (PC10)
/PC11: J7.4, U3.52 (PC11)
/PC12: J7.5, U3.53 (PC12)
/PD2: D2.2 (A), U3.54 (PD2)
/SWCLK: J1.4, U3.49 (PA14)
/SWDIO: J1.2, U3.46 (PA13)
/USB_DN: U1.6 (I/O1), U3.44 (PA11)
/USB_DP: U1.4 (I/O2), U3.45 (PA12)
/nRESET: C1.1, J1.3, SW1.2, U2.2 (~RESET), U3.7 (NRST); also elsewhere on the board
GND: C1.2, C2.2, C3.1, C4.2, C5.1, C7.1, C8.1, C13.1, C14.1, C15.1, C16.1, C17.1, J1.5, J2.A1 (GND), J2.A12 (GND), J2.B1 (GND), J2.B12 (GND), J3.1, J3.8, J3.11, J3.18, J4.1, J5.1, J5.8, J5.11, J5.18, J6.1, J6.8, J6.11, J6.18, J7.1, J7.8, J7.11, J7.18, R1.1, R4.1, R5.2, R6.2, R13.2, R14.2, U1.2 (GND), U2.1 (GND), U3.12 (VSSA), U3.18 (VSS), U3.31 (VSS), U3.47 (VSS), U3.63 (VSS), U4.2 (GND), Y2.2, Y2.4
unnamed: D1.1 (K), R13.1
unnamed: D2.1 (K), R14.1
unnamed: J2.A5 (CC1), R5.1
unnamed: J2.B5 (CC2), R6.1
unnamed: J2.A6 (D+), J2.B6 (D+), U1.3 (I/O2)
unnamed: J2.A7 (D-), J2.B7 (D-), U1.1 (I/O1)
unnamed: J2.S1 (SHIELD), R1.2
unnamed: C8.2, U3.5 (PF0), Y2.1
unnamed: C7.2, U3.6 (PF1), Y2.3
VBUS: C2.1, C3.2, J2.A4 (VBUS), J2.A9 (VBUS), J2.B4 (VBUS), J2.B9 (VBUS), J3.10, J4.2, J5.10, J6.10, J7.10, U1.5 (VBUS), U4.1 (VIN)

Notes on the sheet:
Voltage Supervisor, Hold MCU reset for 150ms after power reaches 2.9V. Prevent brownout at boot.

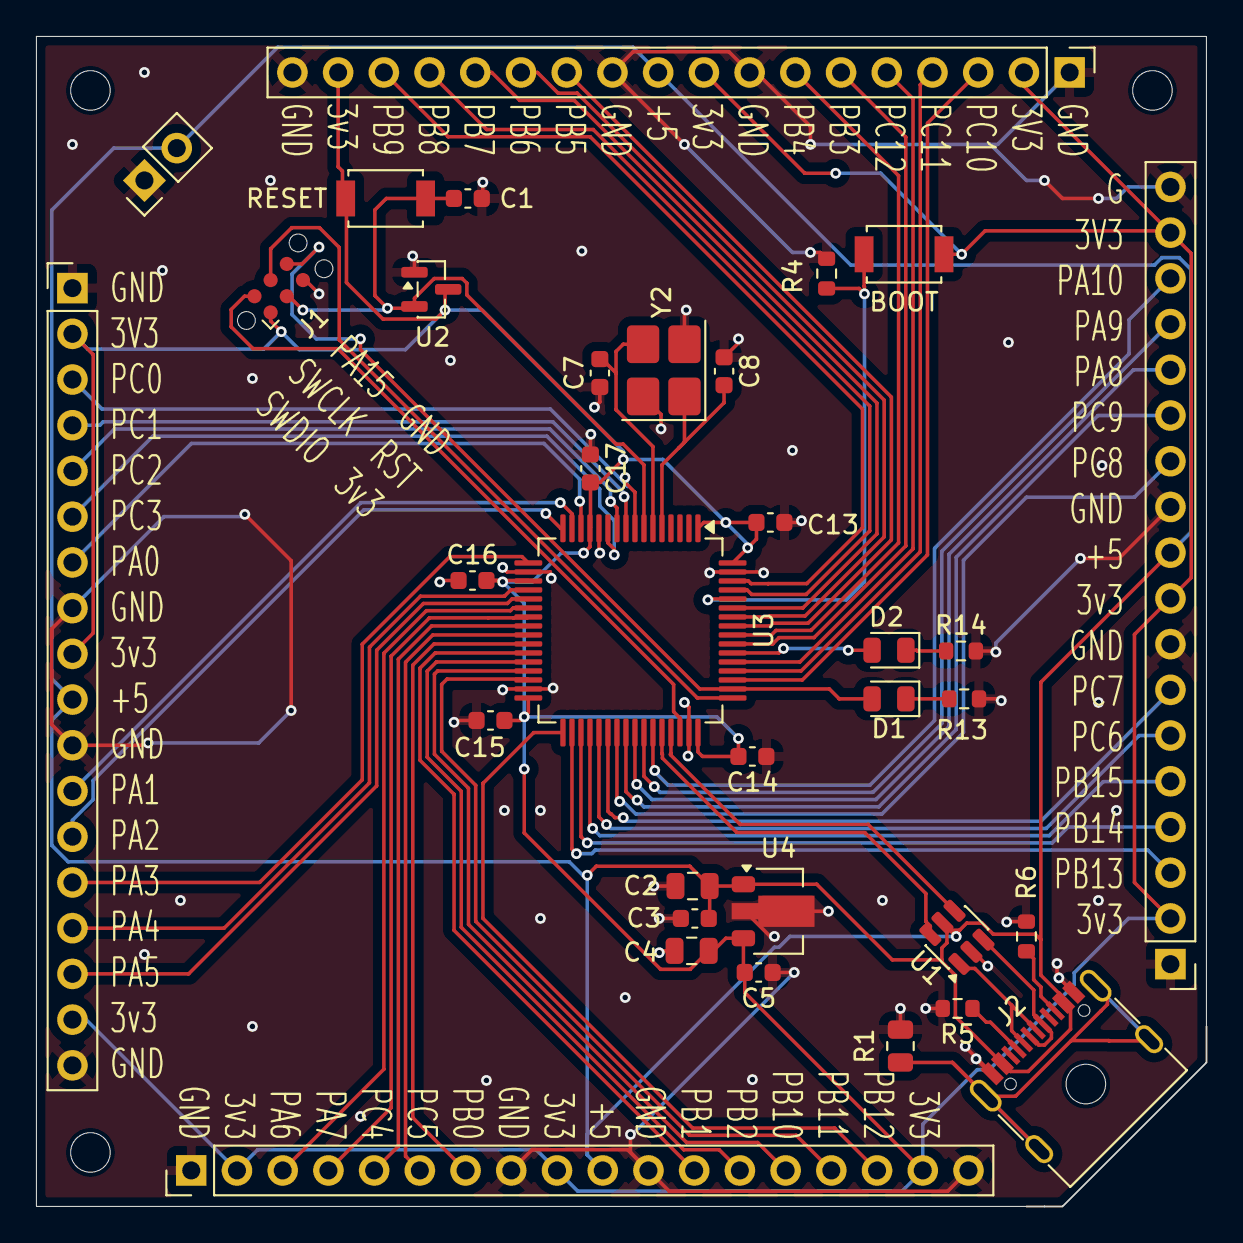
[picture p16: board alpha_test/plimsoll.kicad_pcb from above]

Board: 4 copper layers, 65.0 x 65.0 mm, 38 parts (0 on the bottom side), 60 nets.

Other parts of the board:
BOOT: BOOT0; push_button
RESET: RESET; push_button

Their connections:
+3V3: BOOT.1, RESET.1; also elsewhere on the board
/BOOT0: BOOT.2; also elsewhere on the board
/nRESET: RESET.2; also elsewhere on the board

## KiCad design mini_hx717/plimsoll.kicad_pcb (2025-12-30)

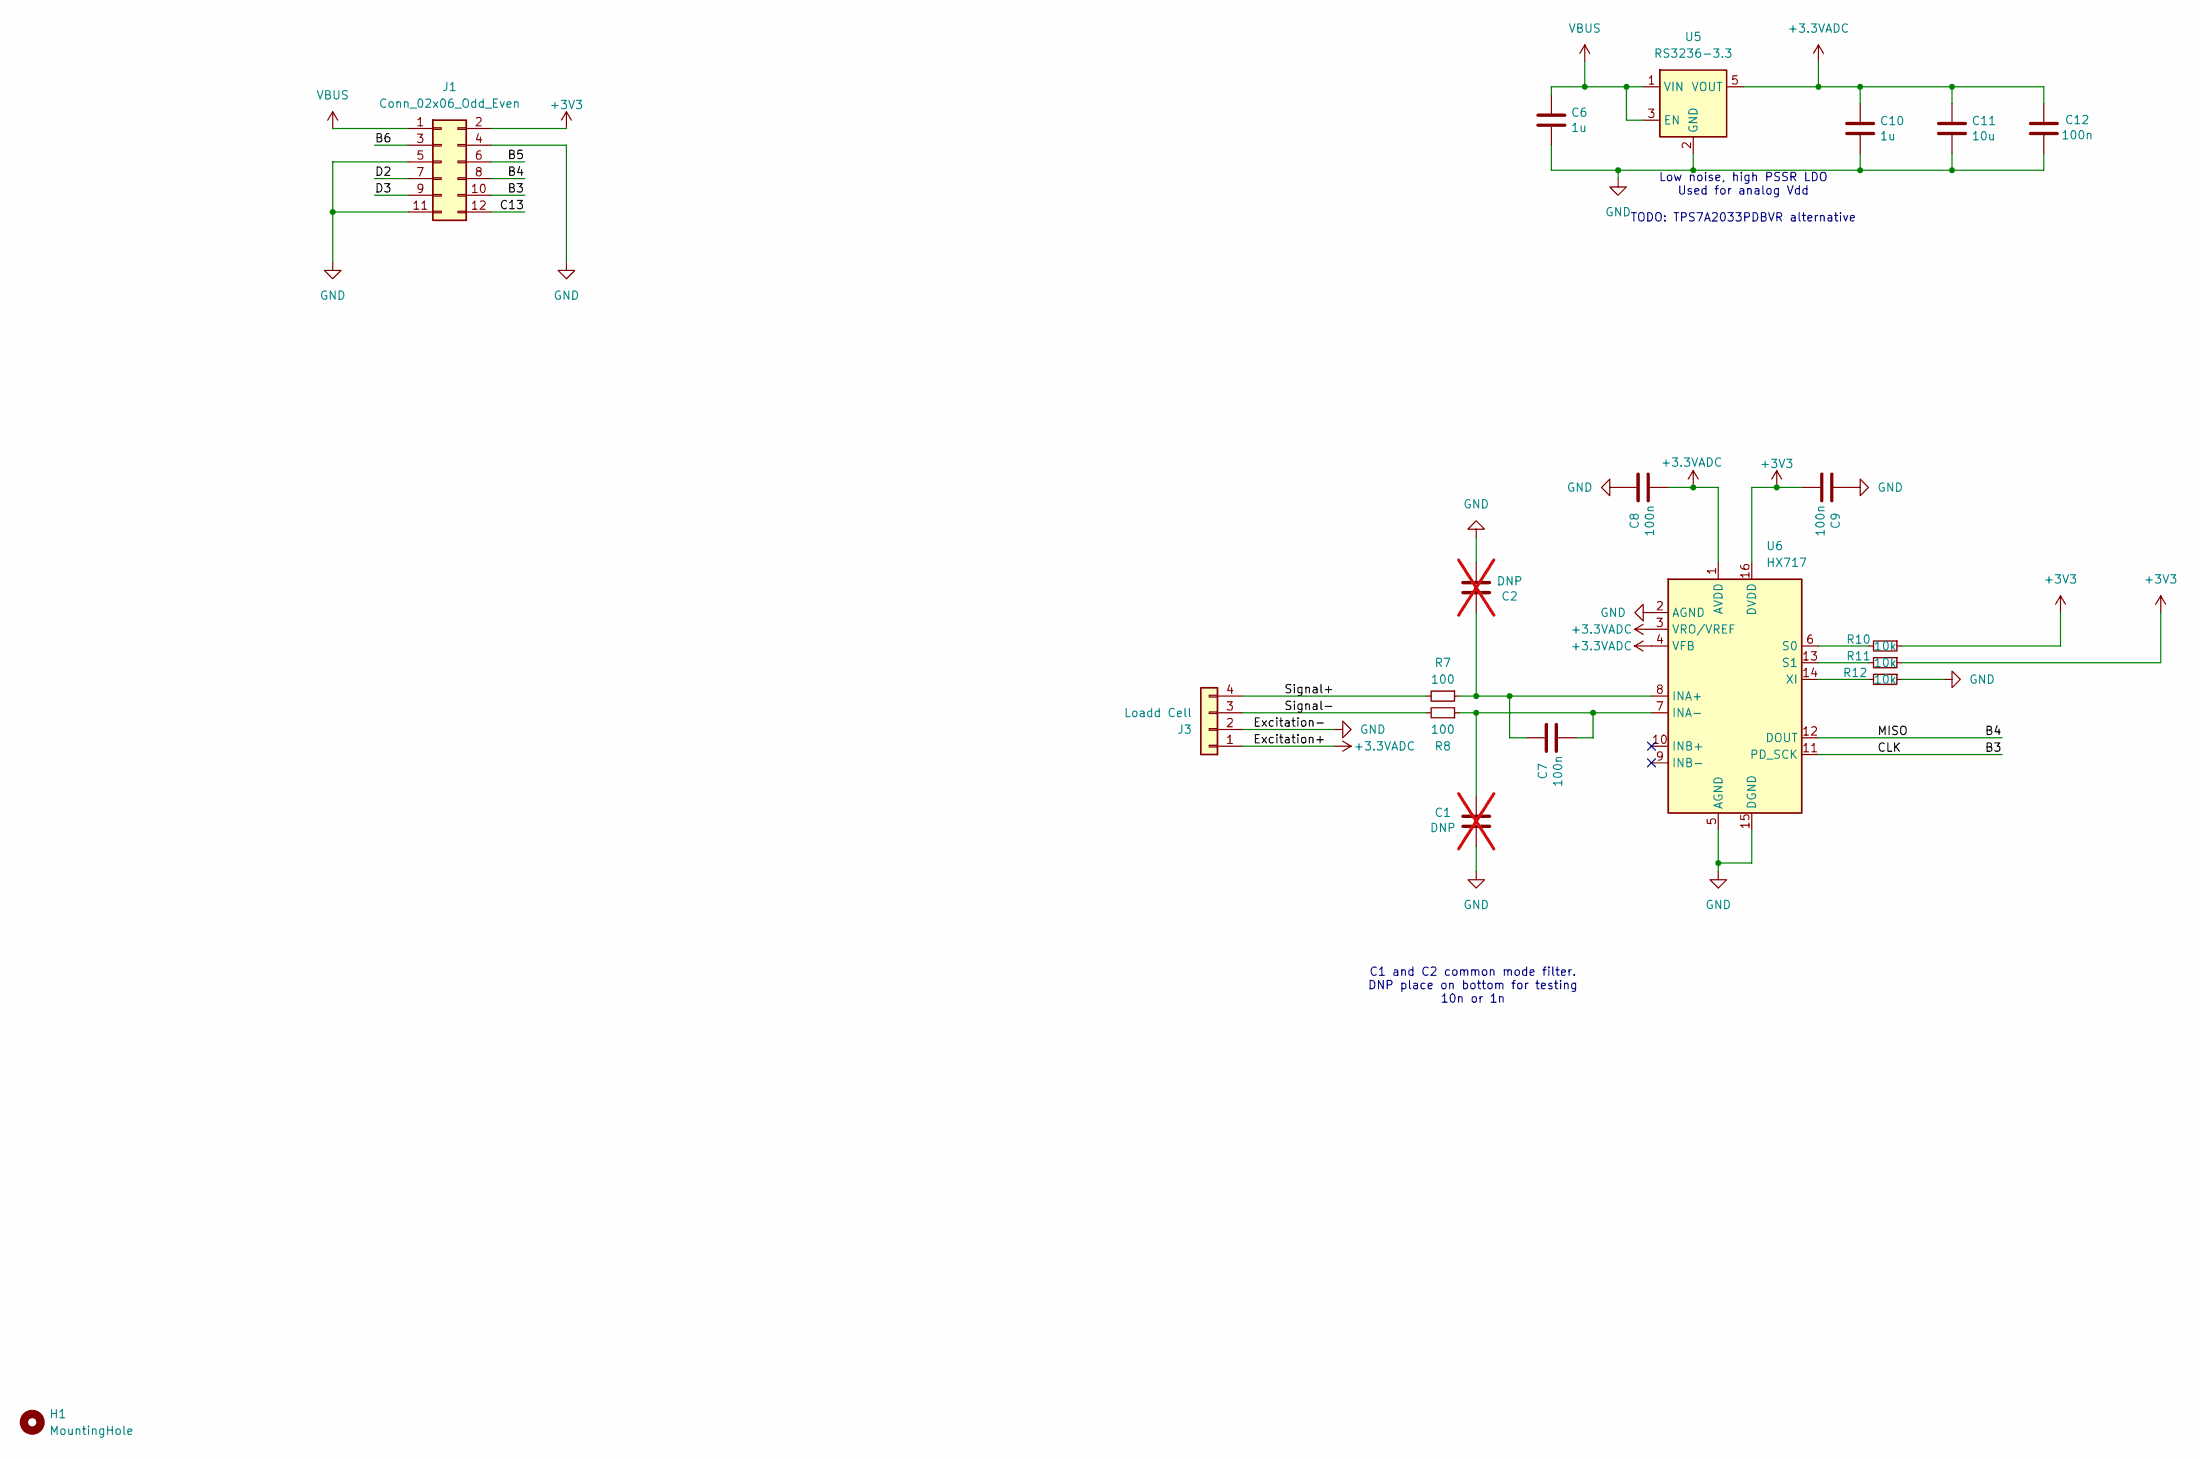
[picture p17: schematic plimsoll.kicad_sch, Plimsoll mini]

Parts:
C1, C2: DNP; C_0603_1608Metric; LCSC PN C14663; not fitted
C6, C10: 1u; C_0805_2012Metric; LCSC PN C28323
C7, C8, C9, C12: 100n; C_0603_1608Metric; LCSC PN C14663
C11: 10u; C_0805_2012Metric; LCSC PN C15850
H1: MountingHole; MountingHole_3.2mm_M3
J1: Conn_02x06_Odd_Even; PinSocket_2x06_P2.00mm_Vertical
J3: Loadd Cell; JST_XH_B4B-XH-A_1x04_P2.50mm_Vertical
R7, R8: 100; R_0603_1608Metric; LCSC PN C22775
R10, R11, R12: 10k; R_0603_1608Metric; LCSC PN C25804
U5: RS3236-3.3; SOT-23-5; LCSC PN C379349
U6: HX717; SOP-16_3.9x9.9mm_P1.27mm; LCSC PN C575394

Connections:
+3.3VADC: C8.1, C10.1, C11.1, C12.2, J3.1, U5.5 (VOUT), U6.1 (AVDD), U6.3 (VRO/VREF), U6.4 (VFB)
+3V3: C9.1, J1.2, R10.1, R11.1, U6.16 (DVDD)
/B3: J1.10, U6.11 (PD_SCK)
/B4: J1.8, U6.12 (DOUT)
/B5: J1.6
/B6: J1.3
/C13: J1.12
/D2: J1.7
/D3: J1.9
/Signal+: J3.4, R7.2
/Signal-: J3.3, R8.2
GND: C1.1, C2.1, C6.2, C8.2, C9.2, C10.2, C11.2, C12.1, J1.4, J1.5, J1.11, J3.2, R12.1, U5.2 (GND), U6.2 (AGND), U6.5 (AGND), U6.15 (DGND)
unnamed: C2.2, C7.2, R7.1, U6.8 (INA+)
unnamed: C1.2, C7.1, R8.1, U6.7 (INA-)
unnamed: R10.2, U6.6 (S0)
unnamed: R11.2, U6.13 (S1)
unnamed: R12.2, U6.14 (XI)
VBUS: C6.1, J1.1, U5.1 (VIN), U5.3 (EN)

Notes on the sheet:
C1 and C2 common mode filter. DNP place on bottom for testing 10n or 1n
Low noise, high PSSR LDO Used for analog Vdd TODO: TPS7A2033PDBVR alternative

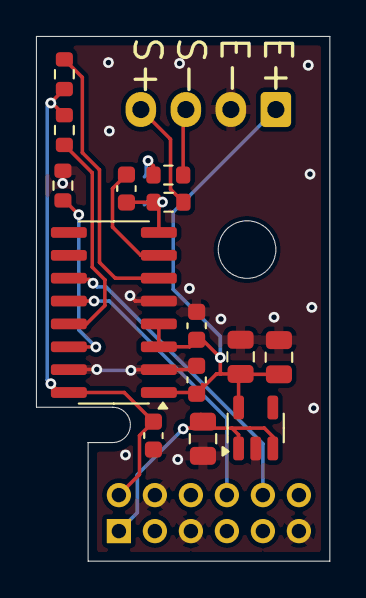
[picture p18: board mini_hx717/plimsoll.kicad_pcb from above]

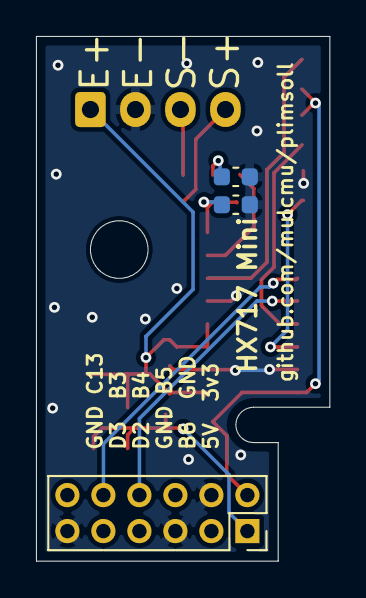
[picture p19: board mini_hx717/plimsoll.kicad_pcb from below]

Board: 4 copper layers, 16.3 x 29.1 mm, 19 parts (3 on the bottom side), 13 nets.

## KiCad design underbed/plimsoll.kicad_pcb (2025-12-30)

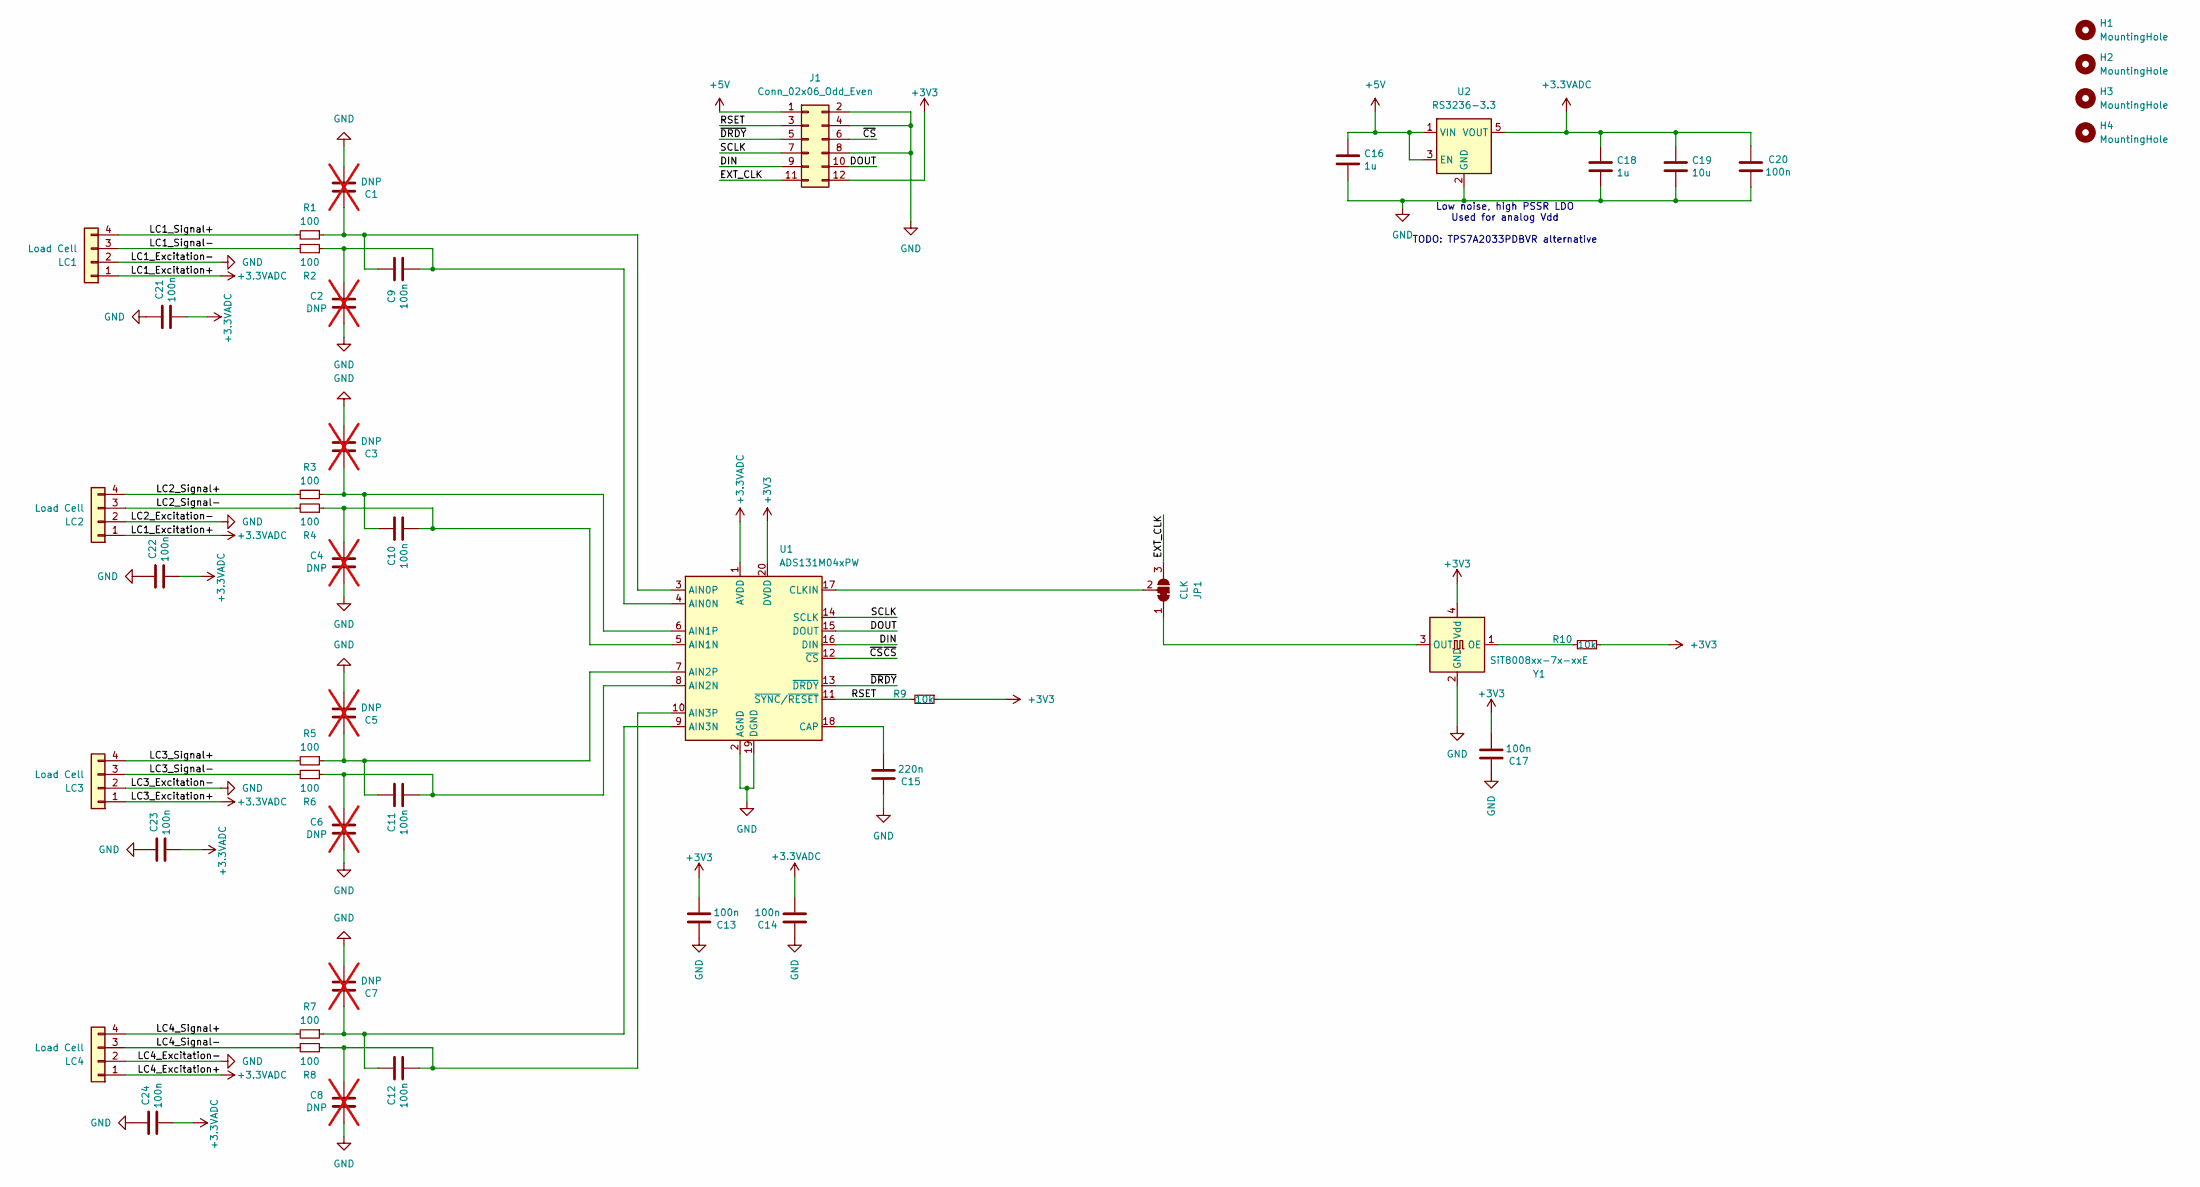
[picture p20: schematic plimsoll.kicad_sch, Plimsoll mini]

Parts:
C1, C2, C3, C4, C5, C6, C7, C8: DNP; C_0603_1608Metric; not fitted
C9, C10, C11, C12, C13, C14, C17, C20, C21, C22, C23, C24: 100n; C_0603_1608Metric; LCSC PN C14663
C15: 220n; C_0603_1608Metric; LCSC PN C21120
C16, C18: 1u; C_0805_2012Metric; LCSC PN C28323
C19: 10u; C_0805_2012Metric; LCSC PN C15850
H1, H2, H3, H4: MountingHole; MountingHole_3.2mm_M3
J1: Conn_02x06_Odd_Even; PinSocket_2x06_P2.54mm_Vertical
JP1: CLK; SolderJumper-3_P1.3mm_Bridged12_RoundedPad1.0x1.5mm_NumberL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
LC1, LC2, LC3, LC4: Load Cell; JST_XH_B4B-XH-A_1x04_P2.50mm_Vertical
R1, R2, R3, R4, R5, R6, R7, R8: 100; R_0603_1608Metric; LCSC PN C22775
R9, R10: 10k; R_0603_1608Metric; LCSC PN C25804
U1: ADS131M04xPW; TSSOP-20_4.4x6.5mm_P0.65mm; LCSC PN C2862562
U2: RS3236-3.3; SOT-23-5; LCSC PN C379349
Y1: SiT8008xx-7x-xxE; Oscillator_SMD_SiT_PQFN-4Pin_2.0x1.6mm; LCSC PN C347672

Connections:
+3.3VADC: C14.1, C18.1, C19.1, C20.2, C21.1, C22.1, C23.1, C24.1, LC1.1, LC2.1, LC3.1, LC4.1, U1.1 (AVDD), U2.5 (VOUT)
+3V3: C13.1, C17.1, J1.12, R9.1, R10.1, U1.20 (DVDD), Y1.4 (Vdd)
+5V: C16.1, J1.1, U2.1 (VIN), U2.3 (EN)
/DIN: J1.9, U1.16 (DIN)
/DOUT: J1.10, U1.15 (DOUT)
/EXT_CLK: J1.11, JP1.3 (B)
/LC1_Signal+: LC1.4, R1.2
/LC1_Signal-: LC1.3, R2.2
/LC2_Signal+: LC2.4, R3.2
/LC2_Signal-: LC2.3, R4.2
/LC3_Signal+: LC3.4, R5.2
/LC3_Signal-: LC3.3, R6.2
/LC4_Signal+: LC4.4, R7.2
/LC4_Signal-: LC4.3, R8.2
/RSET: J1.3, R9.2, U1.11 (~SYNC/~RESET)
/SCLK: J1.7, U1.14 (SCLK)
/~CS: J1.6, U1.12 (~CS)
/~DRDY: J1.5, U1.13 (~DRDY)
GND: C1.1, C2.1, C3.1, C4.1, C5.1, C6.1, C7.1, C8.1, C13.2, C14.2, C15.2, C16.2, C17.2, C18.2, C19.2, C20.1, C21.2, C22.2, C23.2, C24.2, J1.2, J1.4, J1.8, LC1.2, LC2.2, LC3.2, LC4.2, U1.2 (AGND), U1.19 (DGND), U2.2 (GND), Y1.2 (GND)
unnamed: JP1.1 (A), Y1.3 (OUT)
unnamed: JP1.2 (C), U1.17 (CLKIN)
unnamed: C2.2, C9.1, R2.1, U1.4 (AIN0N)
unnamed: C1.2, C9.2, R1.1, U1.3 (AIN0P)
unnamed: C4.2, C10.1, R4.1, U1.5 (AIN1N)
unnamed: C3.2, C10.2, R3.1, U1.6 (AIN1P)
unnamed: C6.2, C11.1, R6.1, U1.8 (AIN2N)
unnamed: C5.2, C11.2, R5.1, U1.7 (AIN2P)
unnamed: C7.2, C12.2, R7.1, U1.9 (AIN3N)
unnamed: C8.2, C12.1, R8.1, U1.10 (AIN3P)
unnamed: C15.1, U1.18 (CAP)
unnamed: R10.2, Y1.1 (OE)

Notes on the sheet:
Low noise, high PSSR LDO Used for analog Vdd TODO: TPS7A2033PDBVR alternative

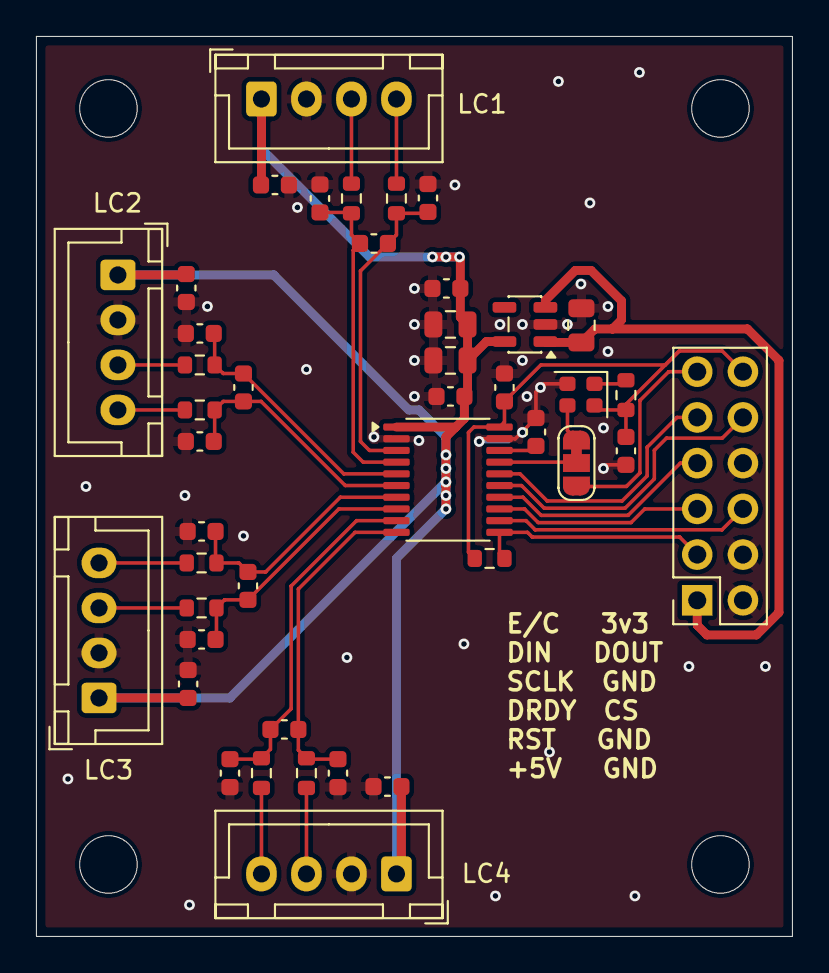
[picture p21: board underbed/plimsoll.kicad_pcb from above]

Board: 4 copper layers, 42.0 x 50.0 mm, 47 parts (0 on the bottom side), 31 nets.

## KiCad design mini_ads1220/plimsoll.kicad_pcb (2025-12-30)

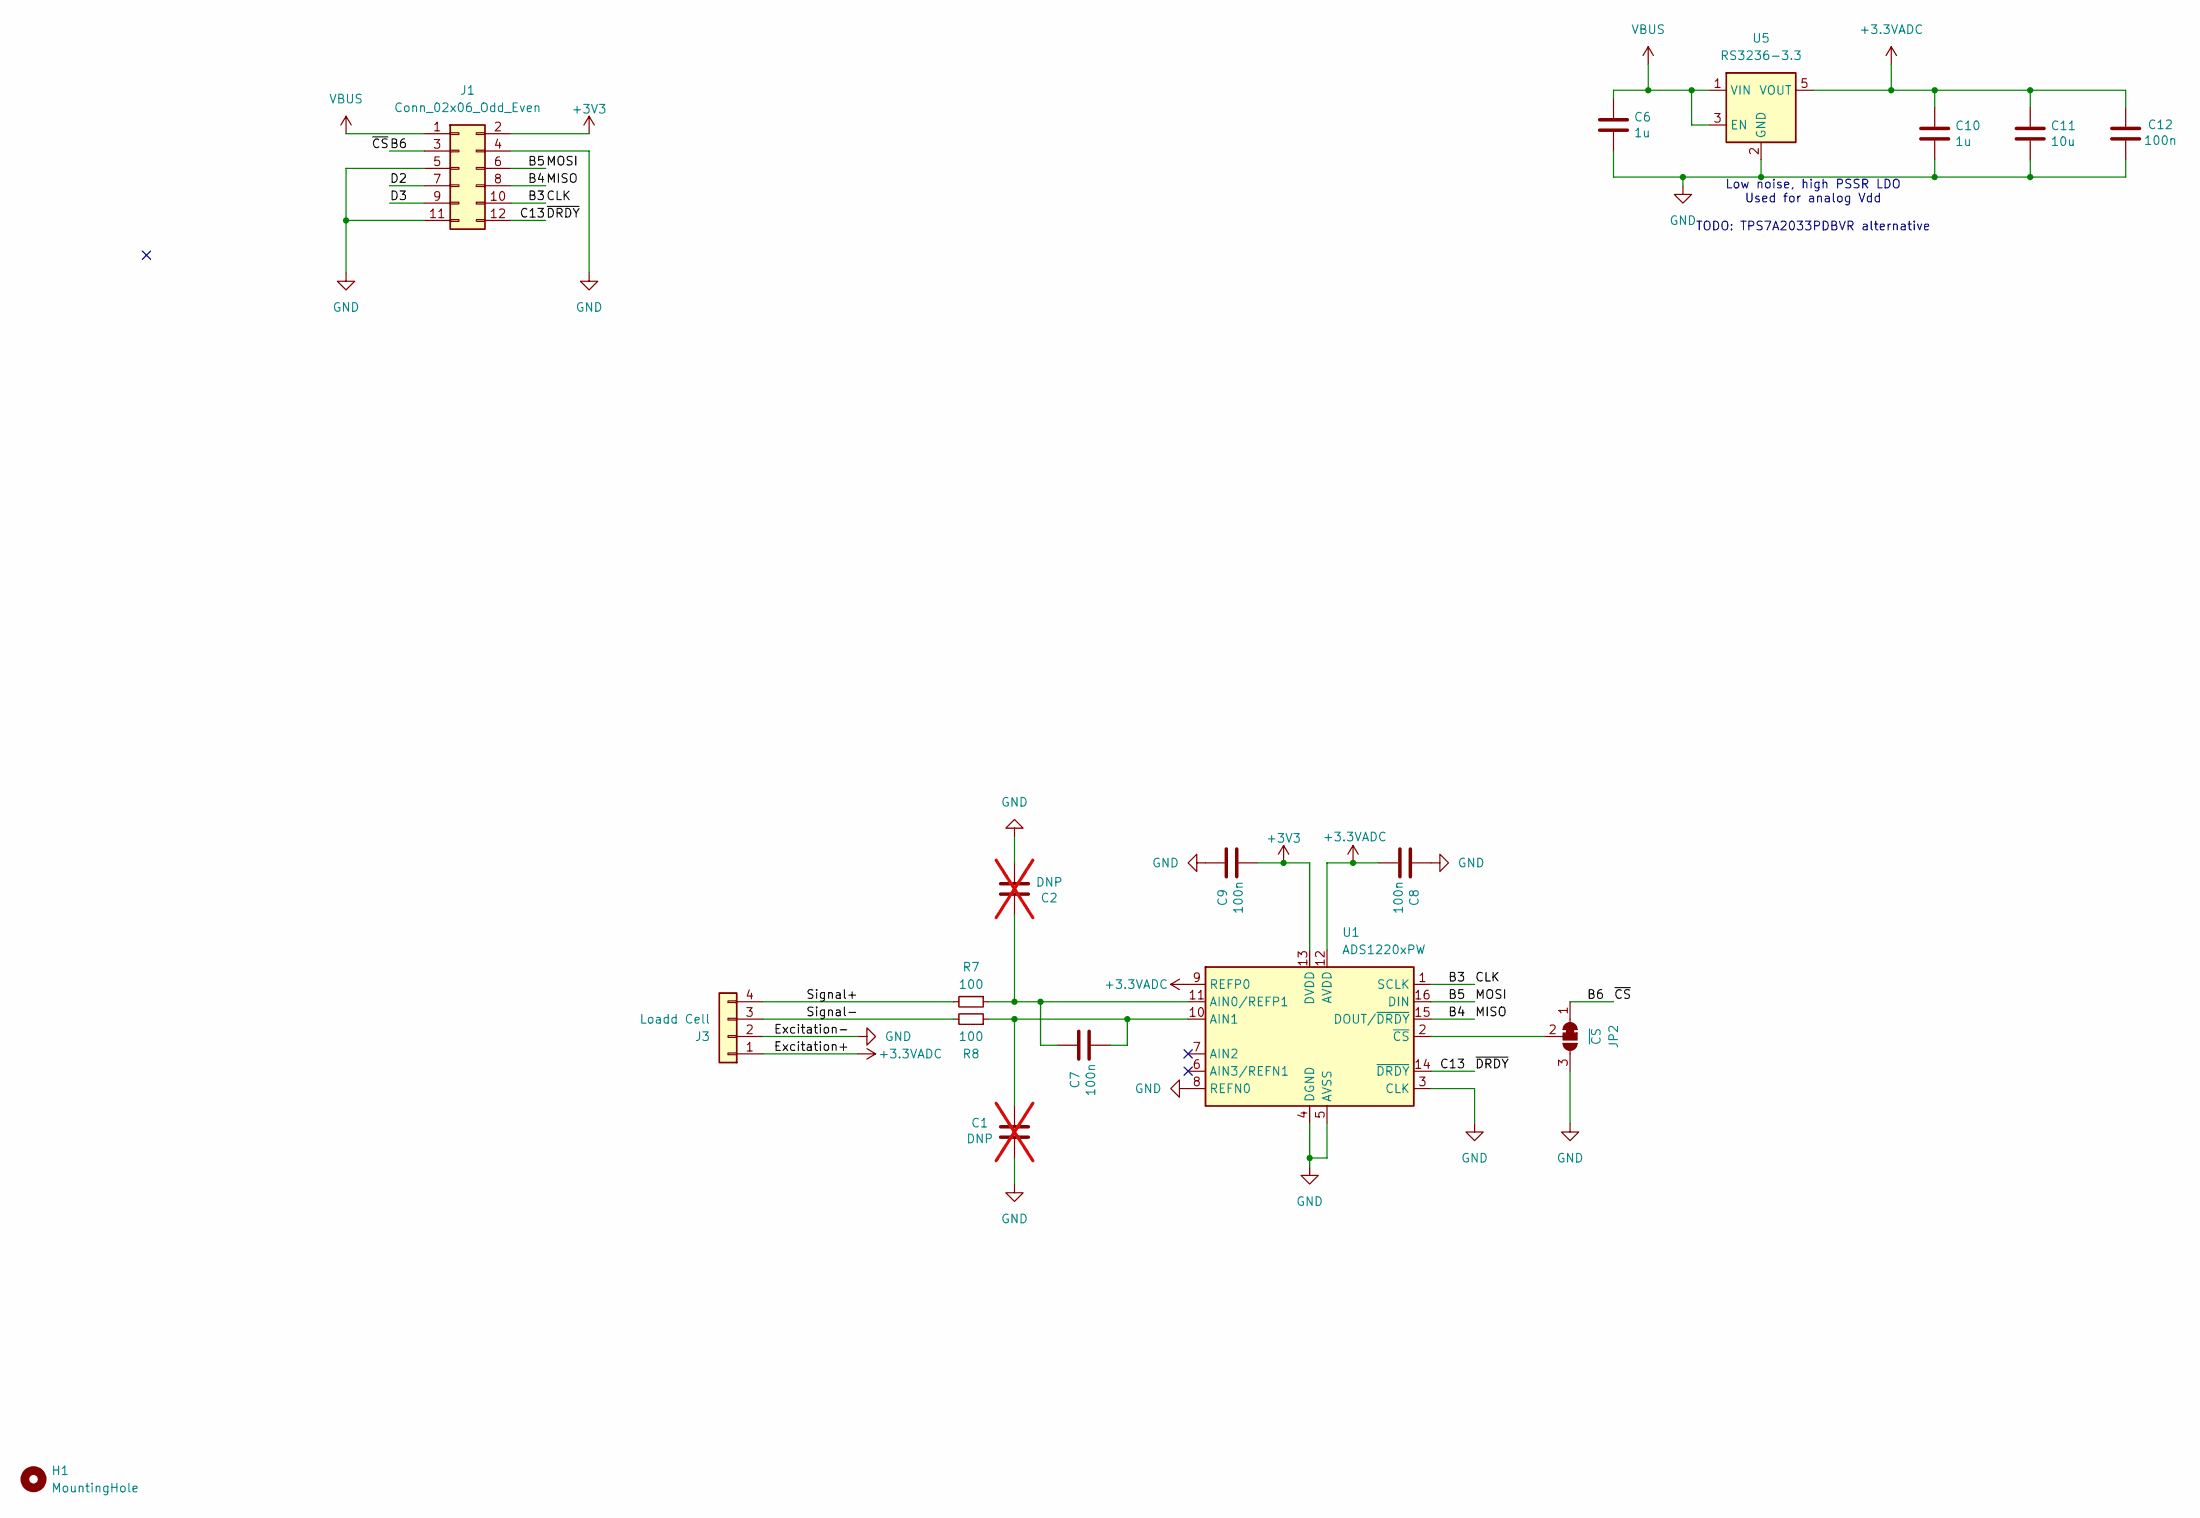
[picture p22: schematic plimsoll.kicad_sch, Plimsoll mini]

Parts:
C1, C2: DNP; C_0603_1608Metric; LCSC PN C14663; not fitted
C6, C10: 1u; C_0805_2012Metric; LCSC PN C28323
C7, C8, C9, C12: 100n; C_0603_1608Metric; LCSC PN C14663
C11: 10u; C_0805_2012Metric; LCSC PN C15850
H1: MountingHole; MountingHole_3.2mm_M3
J1: Conn_02x06_Odd_Even; PinSocket_2x06_P2.00mm_Vertical
J3: Loadd Cell; JST_XH_B4B-XH-A_1x04_P2.50mm_Vertical
JP2: ~{CS}; SolderJumper-3_P1.3mm_Bridged12_RoundedPad1.0x1.5mm_NumberL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
R7, R8: 100; R_0603_1608Metric; LCSC PN C22775
U1: ADS1220xPW; TSSOP-16_4.4x5mm_P0.65mm
U5: RS3236-3.3; SOT-23-5; LCSC PN C379349

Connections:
+3.3VADC: C8.1, C10.1, C11.1, C12.2, J3.1, U1.9 (REFP0), U1.12 (AVDD), U5.5 (VOUT)
+3V3: C9.1, J1.2, U1.13 (DVDD)
/B3: J1.10, U1.1 (SCLK)
/B4: J1.8, U1.15 (DOUT/~DRDY)
/B5: J1.6, U1.16 (DIN)
/B6: J1.3, JP2.1 (A)
/C13: J1.12, U1.14 (~DRDY)
/D2: J1.7
/D3: J1.9
/Signal+: J3.4, R7.2
/Signal-: J3.3, R8.2
GND: C1.1, C2.1, C6.2, C8.2, C9.2, C10.2, C11.2, C12.1, J1.4, J1.5, J1.11, J3.2, JP2.3 (B), U1.3 (CLK), U1.4 (DGND), U1.5 (AVSS), U1.8 (REFN0), U5.2 (GND)
unnamed: JP2.2 (C), U1.2 (~CS)
unnamed: C2.2, C7.2, R7.1, U1.11 (AIN0/REFP1)
unnamed: C1.2, C7.1, R8.1, U1.10 (AIN1)
VBUS: C6.1, J1.1, U5.1 (VIN), U5.3 (EN)

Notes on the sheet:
Low noise, high PSSR LDO Used for analog Vdd TODO: TPS7A2033PDBVR alternative

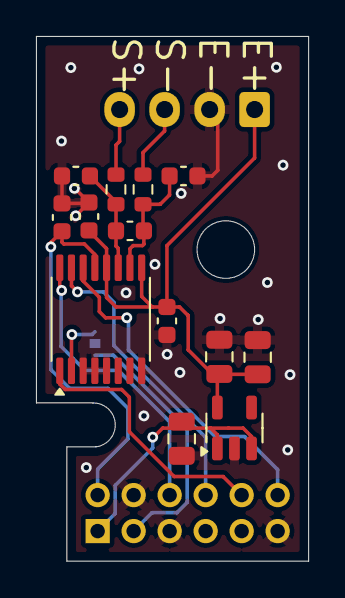
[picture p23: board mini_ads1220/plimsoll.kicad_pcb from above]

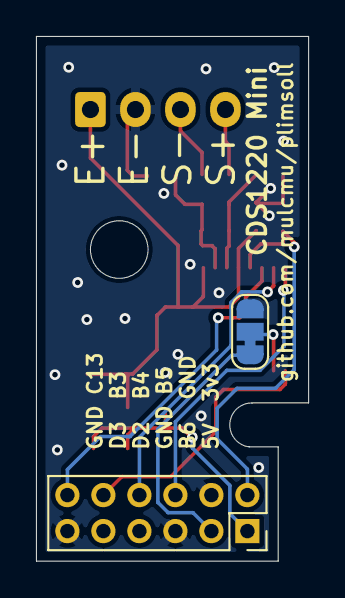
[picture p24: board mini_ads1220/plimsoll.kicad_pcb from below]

Board: 4 copper layers, 15.1 x 29.1 mm, 17 parts (2 on the bottom side), 14 nets.

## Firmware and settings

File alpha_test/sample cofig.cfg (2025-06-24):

#make menuconfig options
# MCU architecture: STM32
# Processor model: STM32F072
# No bootloader offset
# Clock reference: Internal
# Communication interface: USB on PA11/PA12

#optional to have D1 as power led
# Pins to set at startup: PC7

[mcu plimsoll]
serial:  /dev/serial/by-id/usb-Klipper_stm32f072xb_2A0021000B57464232313920-if00
restart_method: command


[load_cell_probe]
sensor_type: hx717
sclk_pin: plimsoll:PC1
dout_pin: plimsoll:PC2
sensor_orientation: inverted
counts_per_gram = 68.54675
reference_tare_counts = 1465556
force_safety_limit: 1000
trigger_force: 75
z_offset: 0.0 #the distance between nozzle and level switch
speed: 2.0
samples: 5 
samples_result: average
sample_retract_dist: 1
samples_tolerance: 0.01
samples_tolerance_retries: 5

#drift_filter_cutoff_frequency: 0.8
#   Enable optional continuous taring while homing & probing to reject drift.
#   The value is a frequency, in Hz, below which drift will be ignored. This
#   option requires the SciPy library. Default: None
buzz_filter_cutoff_frequency: 100.0
#   The value is a frequency, in Hz, above which high frequency noise in the
#   load cell will be igfiltered outnored. This option requires the SciPy
#   library. Default: None
notch_filter_frequencies: 50, 60
#   1 or 2 frequencies, in Hz, to filter out of the load cell data. This is
#   intended to reject power line noise. This option requires the SciPy
#   library. Default: None
#notch_filter_quality: 2.0
#   Controls how narrow the range of frequencies are that the notch filter
#   removes. Larger numbers produce a narrower filter. Minimum value is 0.5 and
#   maximum is 3.0. Default: 2.0
#tare_samples:
#   The number of samples to use when automatically taring the load_cell before
#   each probe. The default value is: sample_per_second * (1 / 60) * 4. This
#   collects samples from 4 cycles of 60Hz mains power to cancel power line
#   noise.
# pullback_distance: 0.2
#   The length of the pullback move. The default is 0.2mm and is a safe
#   starting point for most beds. This can be decreased if the motion system
# is very ridgid
#pullback_speed:
#   The speed of the pullback move. The default value is 1.0 micron per sensor
#   sample. Increasing this value will speed up the move and reduce accuracy.
#tap_buzz_filter_cutoff_frequency: 70
#   Filter out high frequency noise in the probe force data before doing Tap
#   Analysis. Frequencies above this number will be filtered with a
#   Butterworth filter. This option requires the SciPy library. Default: None
#tap_buzz_filter_order: 4
#   This is the order of the Butterworth filter. Higher order numbers
#   increase the complexity of the filter and the sharpness of the cutoff.
#   Default: 4.
notch_filter_frequencies: 50, 60
#   Filter out specific frequencies of noise in the probe force data before
#   doing Tap Analysis. Up to 6 frequencies may be specified. This
#   option requires the SciPy library. Default: None.
notch_filter_quality: 2.0
#   Controls how narrow the range of frequencies are that the tap notch filter
#   removes. Larger numbers produce a narrower filter. Minimum value is 0.5 and
#   maximum is 3.0. Default: 2.0
#bad_tap_retries: 1
#   Number of attempts that the probe shoudld make before failing. One retry
#   will cause the probe to be cleaned once and make a second probe attempt.
#   Default: 1

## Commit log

2025-06-24 r0 build details
    [plimsoll.kicad_sch, sample cofig.cfg]
2025-12-28 add design for mini HX717
    [jlcpcb bom.csv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]
2025-12-29 add ads1220
    [plimsoll.kicad_pcb, plimsoll.kicad_sch, plimsoll.step]
2025-12-29 ads1220 added
    [plimsoll.kicad_pcb, plimsoll.kicad_sch]
2025-12-29 Rewire connector pins and update silkscreen labels
    Reassigned connector pin nets to match new signal mapping, updated silkscreen text to reflect the new pin order, and adjusted related PCB traces and vias. Also made minor component placement tweaks a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
    [plimsoll.kicad_pcb, plimsoll.kicad_sch]
2025-12-30 Add initial KiCad project files for underbed
    [plimsoll.kicad_pcb, plimsoll.kicad_sch]
2025-12-30 Add JLCPCB production files for three PCB projects
    [BOM-plimsoll.csv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]
2025-12-30 Add underbed sensor board documentation and image
    Added documentation for the 4-channel underbed sensor board using ADS131M04 to README.md, including a new image (underbed.png). Updated the todo list to reflect completed design and board ordering.
2026-01-02 Add GitHub Action for automated KiCad schematic PDF generation (#1)
2026-01-03 Commit generated KiCad PDFs to repository (#2)
2026-01-03 Update KiCad schematic PDFs [skip ci]
2026-01-13 Enhance README with pin header and testing info
    Updated the README with additional details on pin header fit and testing tasks.
2026-01-13 updated alpha test for pcb to reuse parts from the alpha test
    [BOM-plimsoll.csv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]
2026-01-14 Update README and add installation images
    Improved documentation for the mini_ads1220 board, clarified header and standoff fitment details, added Klipper configuration examples, and marked mini board tests as complete. Added two images showi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
